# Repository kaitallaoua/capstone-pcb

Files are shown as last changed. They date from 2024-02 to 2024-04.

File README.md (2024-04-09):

# Analog Circuit Reliability for Low Earth Orbit Space Applications

In collaboration with the University of Saskatchewan, we are contributing a payload board
for the CubeSats Initiative in Canada for STEM (CUBICS). A CubeSat is a low cost, small
and approachable design for students “to engage in an end-to-end space mission
adapted to their needs and their level of comfort, expertise and readiness” (asc-csa.
gc.ca). Our payload studies the effects of space radiation on commonly used surface
mount analog Integrated Circuits (IC’s) in Low Earth Orbit (LEO). We compare different
shielding to see which provides a better effectiveness to weight ratio.

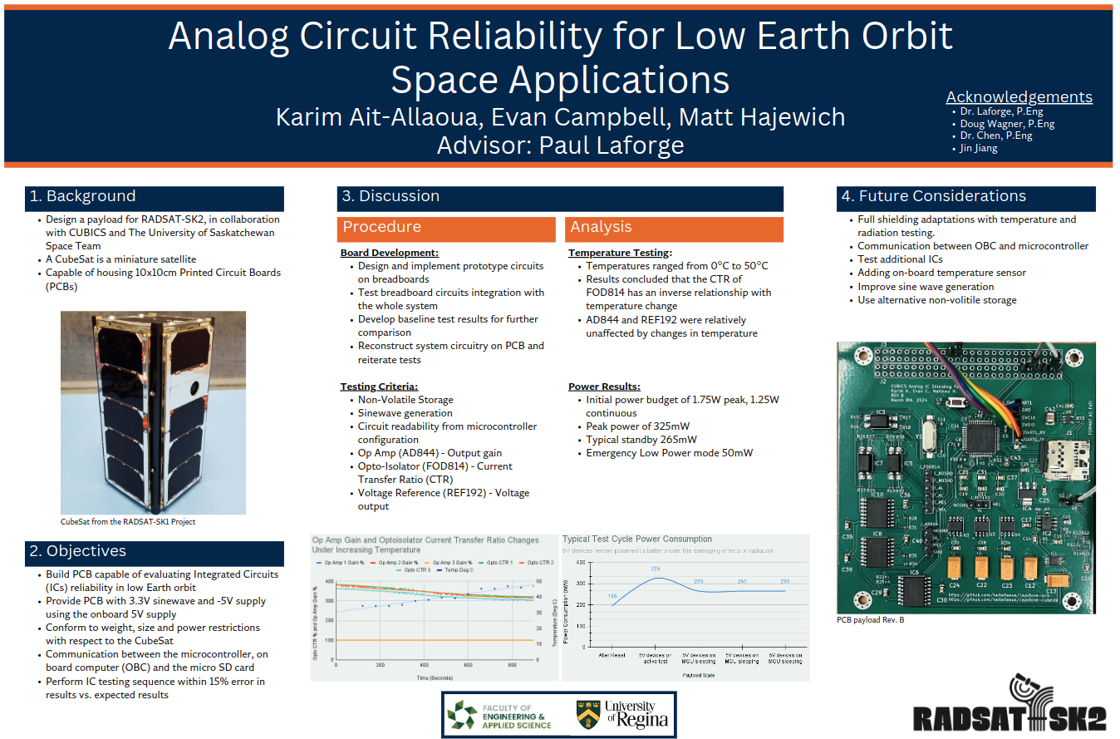
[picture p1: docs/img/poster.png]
poster


## Software

Available [here](https://github.com/kaitallaoua/capstone-cubeide)

## Setup

This project used KiCad `Version: 7.0.11-7.0.11~ubuntu22.04.1, release build` and a mix of windows builds.
Download KiCad [here](https://www.kicad.org/download/). KiCad 8 likely does work and I recommend you use it.

## Workflow

TBD (remove this once done): Someone needs to fork this repo to make further contributions to the project. Using an organization is best, I think UofS space team has one, maybe Regina team should make one? Regardless I will not be reviewing and accepting PR's to this repo.

Because using git for KiCad is like tracking binary files, I recommend to NOT rely on git handling merge conflicts. Avoid them entirely by letting only one person make changes on one branch at a time, make a PR, approve and merge and repeat and pass the baton to someone else to make changes.

## TODO

- Get I2C working (unlikely any KiCad changes)
- Get sinewave generation working 
- Add Voltage regulator
- Triple check we fit in PC104, on RADSAT-SK1 printout we dont fit in all holes, also supposed to be some notches?
- Optional: Use solder-attched external non volatile storage such as FLASH, EEPROM (or solder/glue micro sd down??)

The most substantial changes the sinwave generation. This task was assigned to Evan. Ultimately we could not get it working, thus I recommend to use a PWM wave gen from the mcu, likely add pre-amplification + current buffering, and pass it to a sharp drop off filter. The filter could be a dedicated one (probably better) or an op-amp driven one (butterworth?, wont have as good drop off without many stages).

UofRobotics is also making a PCB for their robot whose base is forked from this project, they may be a good reference for questions or idea sharing.

## Manufacturing

We used JLCPCB for `REV A` and `REV B` with great results. We also have nearly all parts ready for another revision. AT LEAST ONE MORE REVISION IS NEEDED SINCE THE FOLLOWING WERE FIXED AFTER `REV B`:

- IC1 footprint solder mask was incorrectly removed
- Micro SD card holder was facing the wrong way

Our manufacturing procedure was as follows:

Order from JLC (1 week delivery), Order from Mouser/Digikey (2-4 day delivery) -> Have all parts -> Go to ED435, use microscope, have one person assist finding parts, one pick+place, apply solder paste (min 4-5 hours)-> place in oven -> done

I recommend to use the parts list available from JLCPCB or PCBWay to assemble as much of the board for you as possible, it saves alot of time but honestly building it by hand it also not that bad. Either is fine.

## Resources

[KiCad 6 STM32 PCB Design Full Tutorial - Phil's Lab #65](https://www.youtube.com/watch?v=aVUqaB0IMh4)

[PCB Design Final Touches (Tips & Checklist) - Phil's Lab #131](https://www.youtube.com/watch?v=g4m91gv-4oQ)

## Front PCB

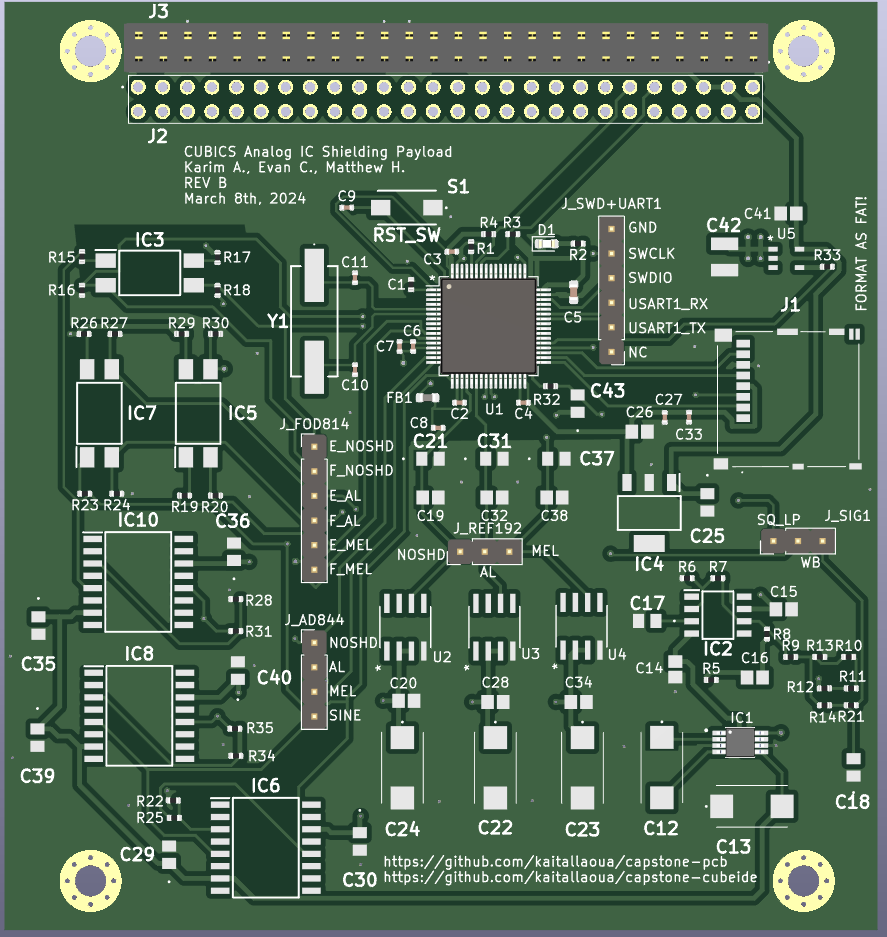
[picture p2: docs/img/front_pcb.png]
front_pcb


## Back PCB

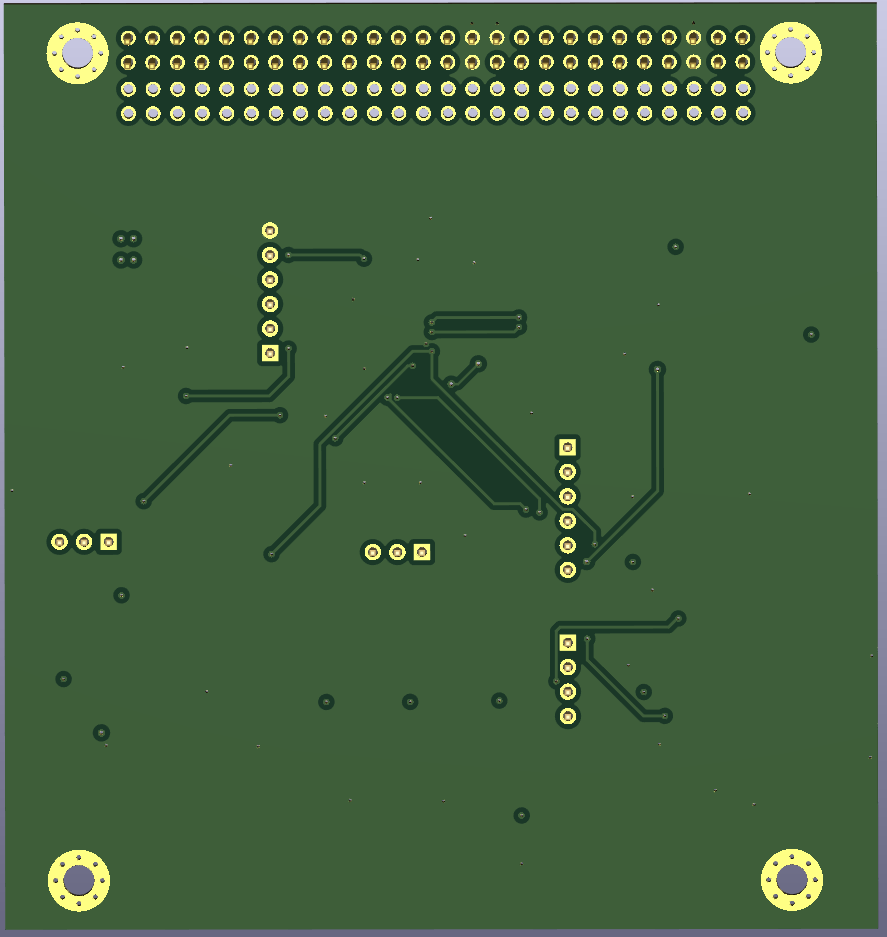
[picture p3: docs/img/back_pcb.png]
back_pcb


## Front Copper Layer

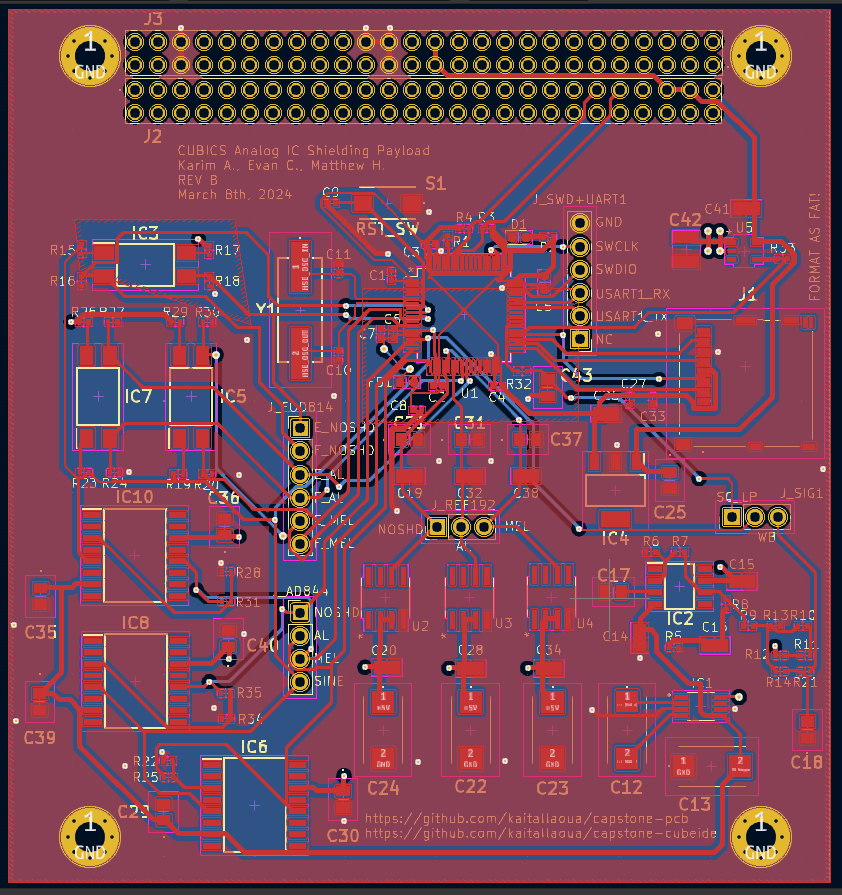
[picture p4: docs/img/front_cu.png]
front_cu


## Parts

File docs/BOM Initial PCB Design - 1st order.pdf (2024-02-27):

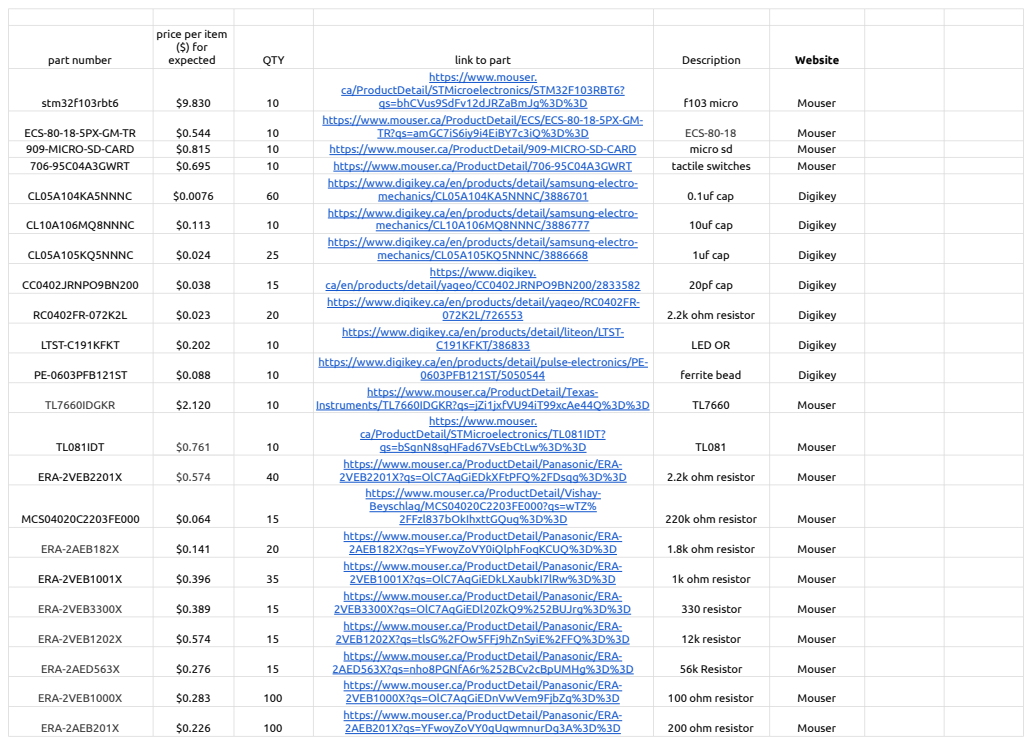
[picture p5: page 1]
part number; QTY; link to part; Description; Website; stm32f103rbt6; qs=bhCVus9SdFv12dJRZaBmJg%3D%3D; f103 micro; Mouser; ECS-80-18-5PX-GM-TR; TR?qs=amGC7iS6iy9i4EiBY7c3iQ%3D%3D; ECS-80-18; 909-MICRO-SD-CARD; https://www.mouser.ca/ProductDetail/909-MICRO-SD-CARD; micro sd; 706-95C04A3GWRT; https://www.mouser.ca/ProductDetail/706-95C04A3GWRT; tactile switches; CL05A104KA5NNNC; mechanics/CL05A104KA5NNNC/3886701; 0.1uf cap; Digikey; CL10A106MQ8NNNC; mechanics/CL10A106MQ8NNNC/3886777; 10uf cap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

price per item
($) for
expected

https://www.mouser.

ca/ProductDetail/STMicroelectronics/STM32F103RBT6?

https://www.mouser.ca/ProductDetail/ECS/ECS-80-18-5PX-GM-

https://www.digikey.ca/en/products/detail/samsung-electro-

https://www.digikey.

https://www.digikey.ca/en/products/detail/yageo/RC0402FR-

https://www.digikey.ca/en/products/detail/liteon/LTST-

https://www.digikey.ca/en/products/detail/pulse-electronics/PE-

https://www.mouser.ca/ProductDetail/Texas-

ca/ProductDetail/STMicroelectronics/TL081IDT?

https://www.mouser.ca/ProductDetail/Panasonic/ERA-
https://www.mouser.ca/ProductDetail/Vishay-
Beyschlag/MCS04020C2203FE000?qs=wTZ%

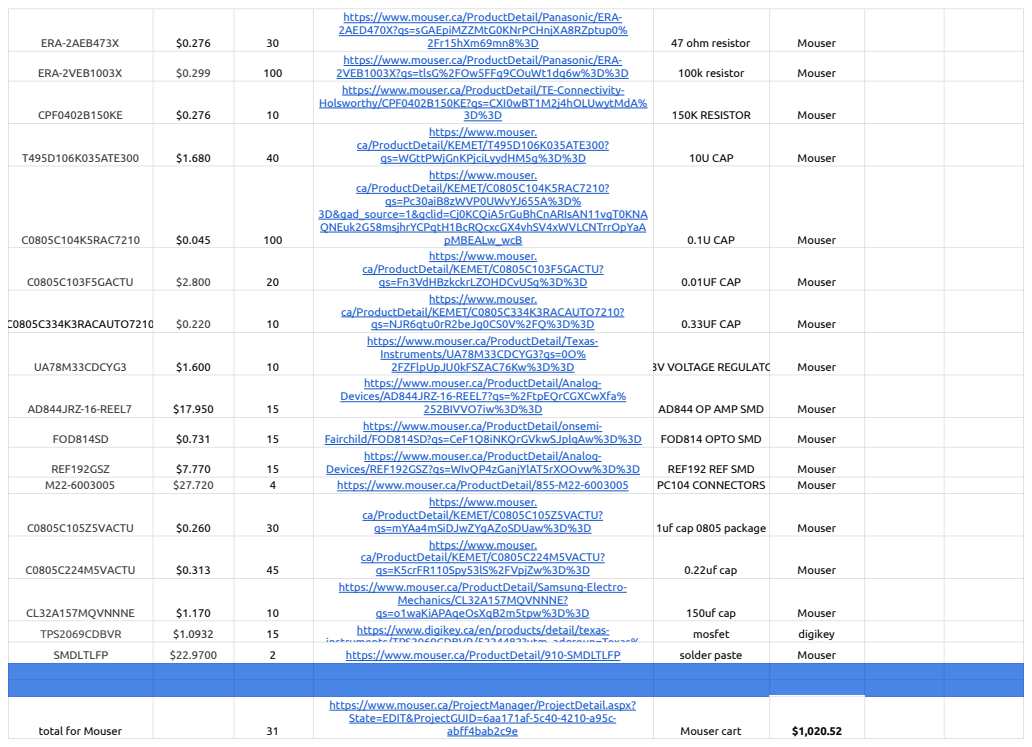
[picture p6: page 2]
ERA-2AEB473X; 2Fr15hXm69mn8%3D; 47 ohm resistor; Mouser; ERA-2VEB1003X; 2VEB1003X?qs=tlsG%2FOw5FFg9COuWt1dq6w%3D%3D; 100k resistor; CPF0402B150KE; 150K RESISTOR; T495D106K035ATE300; qs=WGttPWjGnKPjciLyydHM5g%3D%3D; 10U CAP; C0805C104K5RAC7210; 3D&gad_source=1&gclid=Cj0KCQiA5rGuBhCnARIsAN11vgT0KNA QNEuk2G58msjhrYCPqtH1BcRQcxcGX4vhSV4xWVLCNTrrOpYaA; pMBEALw_wcB; 0.1U CAP; C0805C103F5GACTU; qs=Fn3VdHBzkckrLZOHDCvUSg%3D%3D; 0.01UF CAP; C0805C334K3RACAUTO7210; qs=NJR6qtu0rR2beJg0CS0V%2FQ%3D%3D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

https://www.mouser.ca/ProductDetail/Panasonic/ERA-
2AED470X?qs=sGAEpiMZZMtG0KNrPCHnjXA8RZptup0%

https://www.mouser.ca/ProductDetail/TE-Connectivity-
Holsworthy/CPF0402B150KE?qs=CXI0wBT1M2j4hOLUwytMdA%

https://www.mouser.

ca/ProductDetail/KEMET/T495D106K035ATE300?

ca/ProductDetail/KEMET/C0805C104K5RAC7210?
qs=Pc30aiB8zWVP0UWvYJ655A%3D%

ca/ProductDetail/KEMET/C0805C103F5GACTU?

ca/ProductDetail/KEMET/C0805C334K3RACAUTO7210?
https://www.mouser.ca/ProductDetail/Texas-
Instruments/UA78M33CDCYG3?qs=0O%
https://www.mouser.ca/ProductDetail/Analog-
Devices/AD844JRZ-16-REEL7?qs=%2FtpEQrCGXCwXfa%

https://www.mouser.ca/ProductDetail/onsemi-

ca/ProductDetail/KEMET/C0805C105Z5VACTU?

ca/ProductDetail/KEMET/C0805C224M5VACTU?

https://www.mouser.ca/ProductDetail/Samsung-Electro-

https://www.mouser.ca/ProjectManager/ProjectDetail.aspx?
State=EDIT&ProjectGUID=6aa171af-5c40-4210-a95c-

total for Digikey | 8 | https://www.digikey.ca/short/bmjnbp47 | Digikey cart | 33.18
total cart | 39 | TOTAL | $1,053.70 | Tax might not | be included

https://www.mouser.
ca/ProductDetail/KEMET/C0805C334K3RACAUTO?
qs=sSYV1F9c5cFAGgBePUAC4A%3D%3D (https://www.mouser.ca/ProductDetail/KEMET/C0805C334K3RACAUTO?qs=sSYV1F9c5cFAGgBePUAC4A%3D%3D) | .33uf new

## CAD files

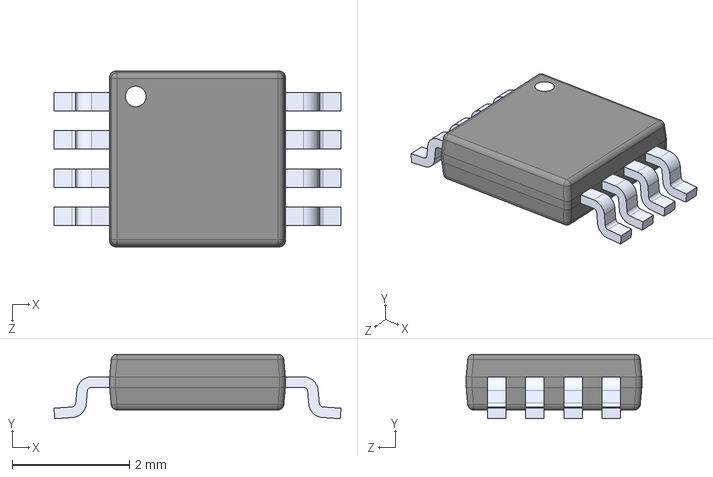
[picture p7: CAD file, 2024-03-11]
footprint_3d/TL7660IDGKR.step
4.90 x 1.10 x 3.00 mm

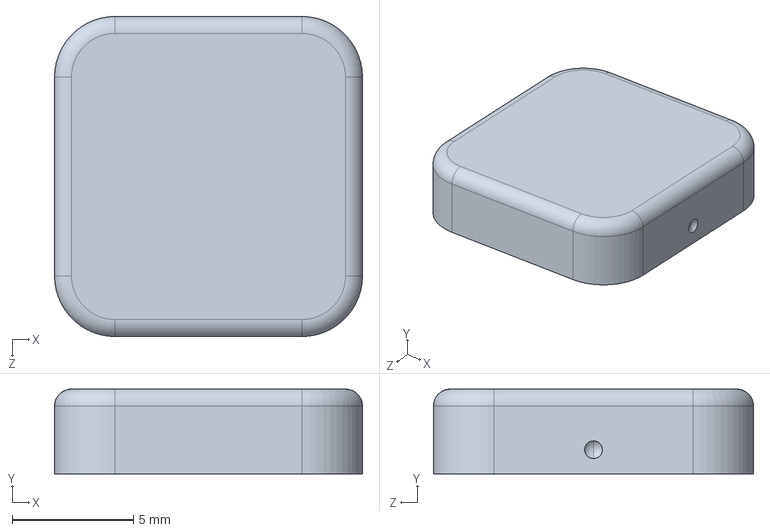
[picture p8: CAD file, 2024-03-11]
footprint_3d/MS128-10C.step
12.7 x 3.50 x 13.2 mm

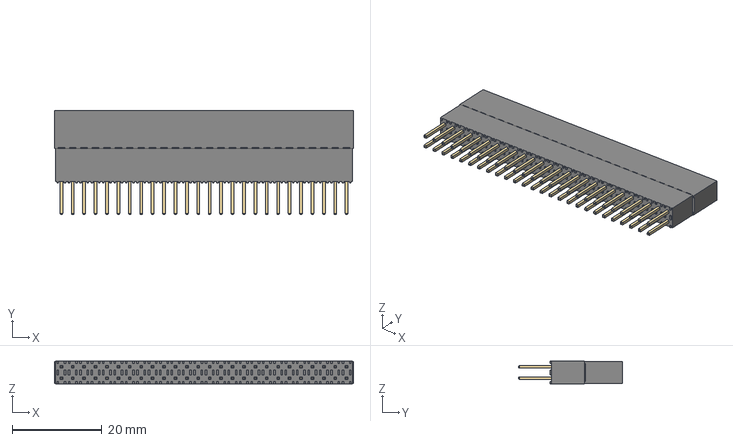
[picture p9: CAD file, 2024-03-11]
footprint_3d/ESQ-126-39-L-D.stp
66.5 x 23.2 x 5.08 mm

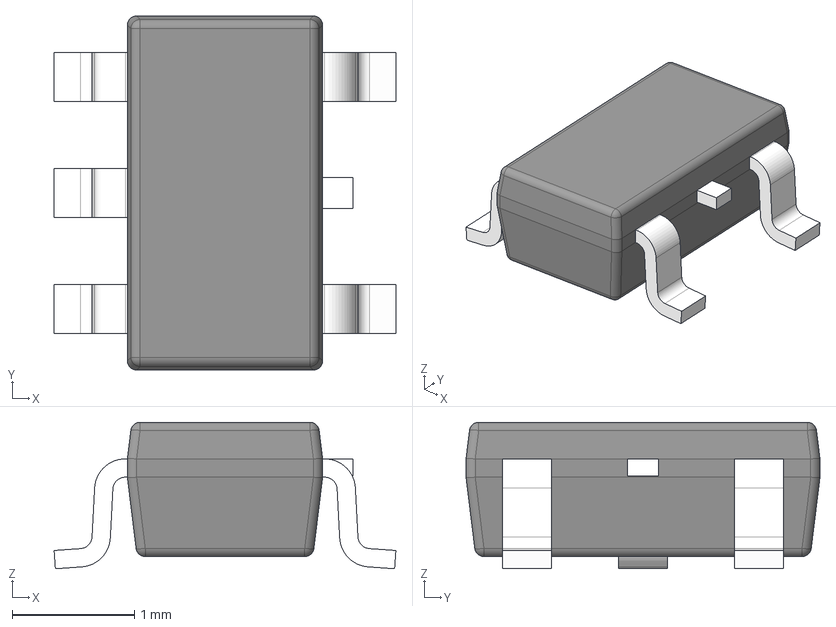
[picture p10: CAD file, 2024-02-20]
footprint_3d/DBV0005A-MF.stp
2.80 x 2.90 x 1.20 mm
BODY-SOT
LEAD-SOT x 5
LEAD-DUMMY

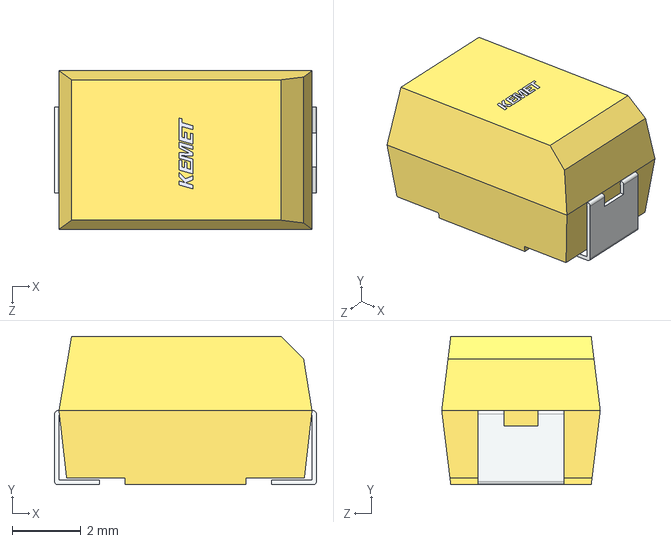
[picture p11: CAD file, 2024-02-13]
footprint_3d/T495X106K050ATE250-10u.stp
7.60 x 4.31 x 4.60 mm

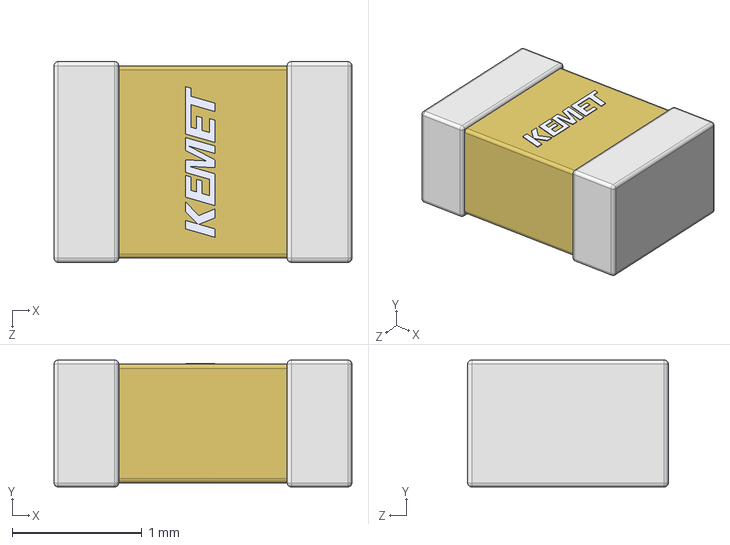
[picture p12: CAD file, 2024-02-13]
footprint_3d/C0805C224M5VACTU-0.22u.stp
2.30 x 0.98 x 1.55 mm

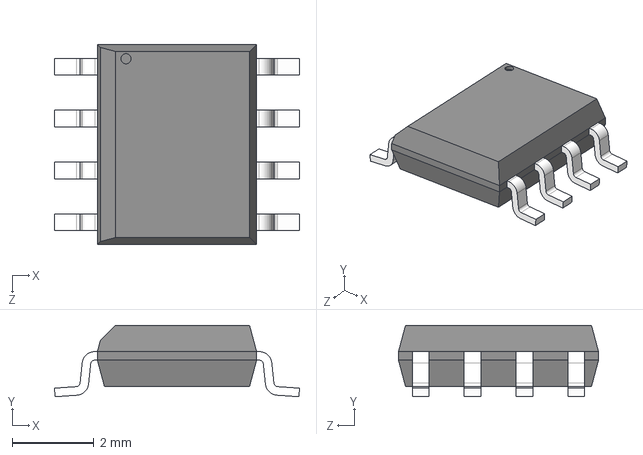
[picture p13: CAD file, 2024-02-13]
footprint_3d/REF192GSZ.step
6.00 x 1.75 x 4.90 mm

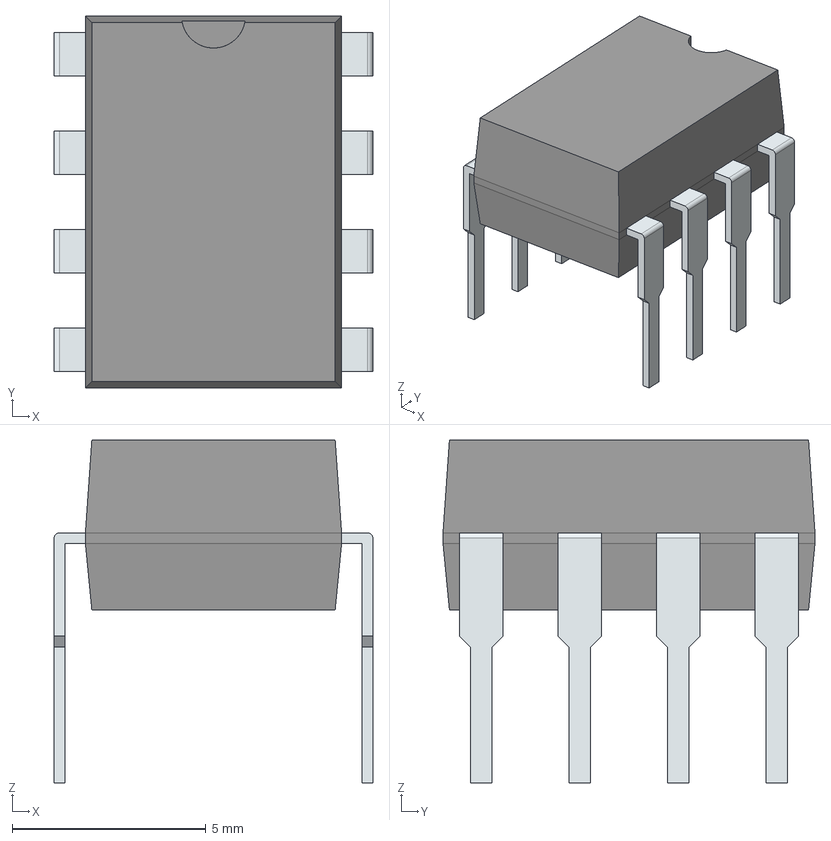
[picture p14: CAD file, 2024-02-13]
footprint_3d/AD844ANZ.stp
8.22 x 9.59 x 8.83 mm
PinsArrayLR

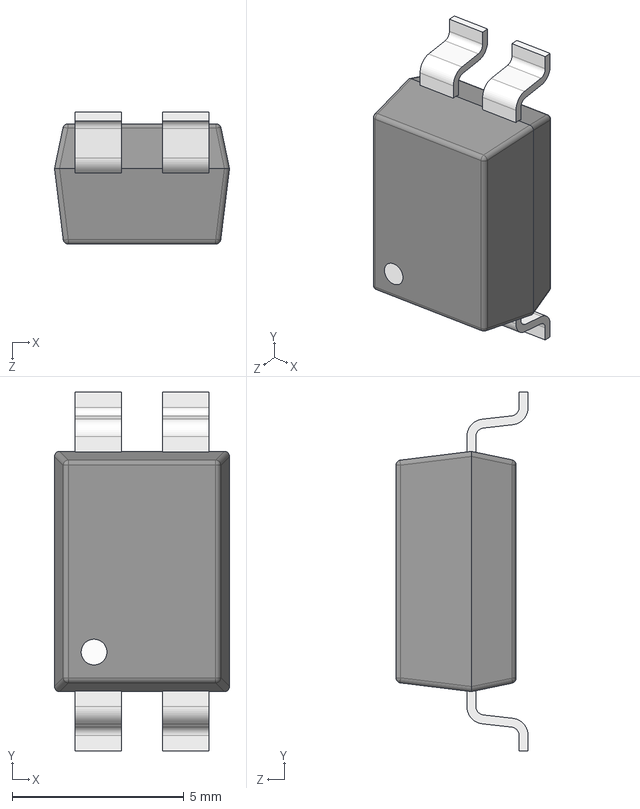
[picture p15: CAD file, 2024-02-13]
footprint_3d/FOD814SD.stp
5.10 x 10.5 x 3.85 mm

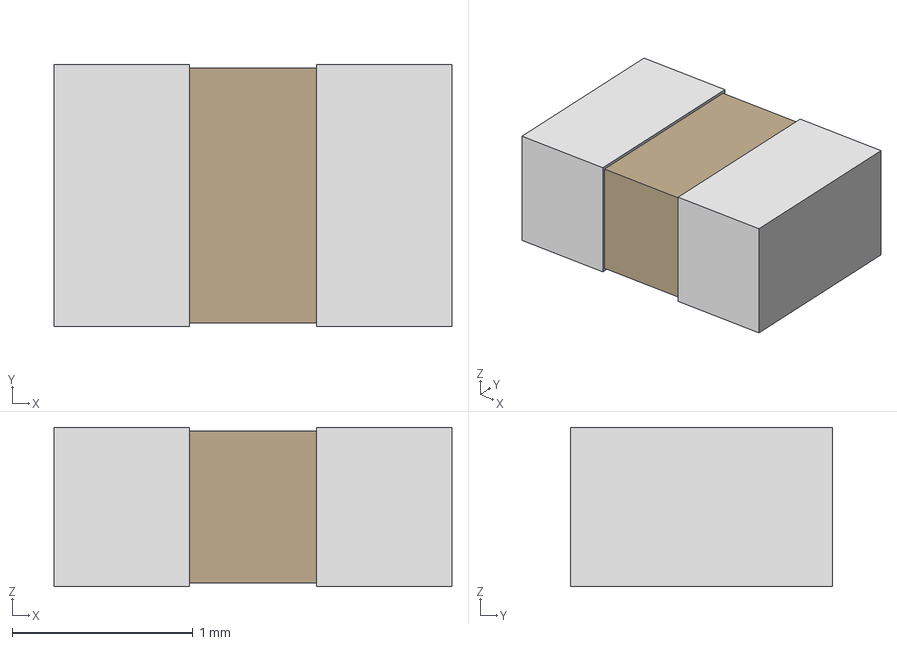
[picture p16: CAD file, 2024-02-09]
footprint_3d/CAPC220145_88N_KEM.step
2.20 x 1.45 x 0.88 mm

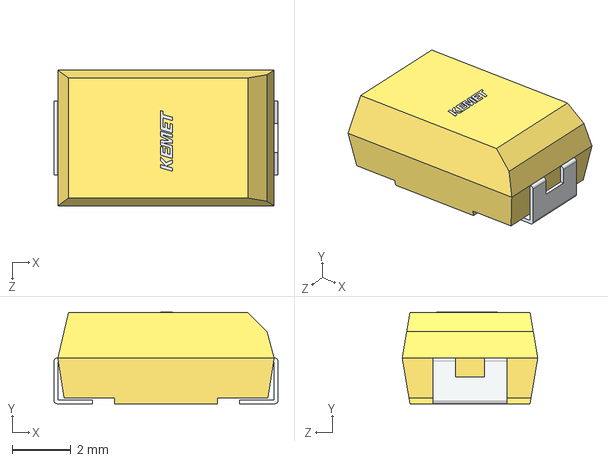
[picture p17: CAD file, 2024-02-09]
footprint_3d/T495D106K035ATE300.stp
7.60 x 3.11 x 4.60 mm

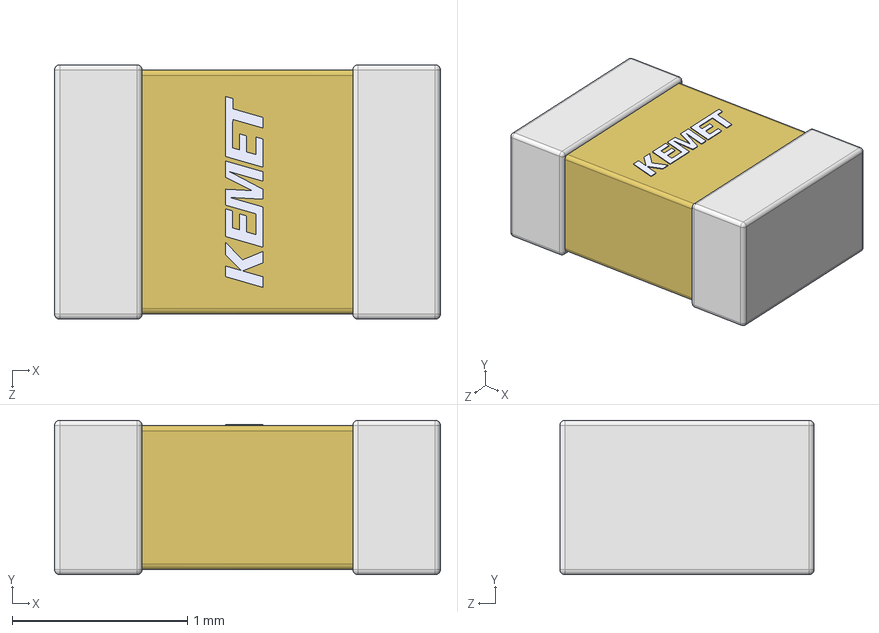
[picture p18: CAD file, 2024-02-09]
footprint_3d/C0805C103F5GACTU.stp
2.20 x 0.88 x 1.45 mm

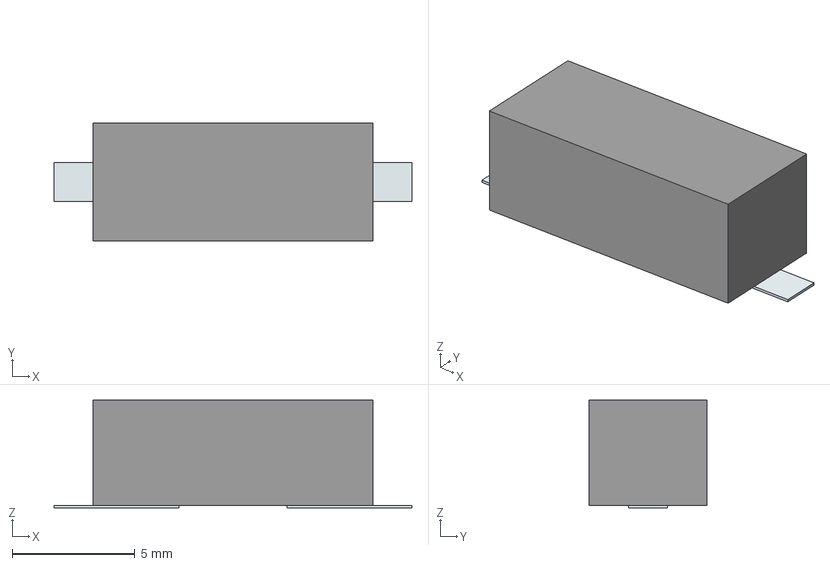
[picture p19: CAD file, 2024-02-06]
footprint_3d/ECS-80-18-5PX-GM-TR.stp
14.6 x 4.80 x 4.40 mm
Pins

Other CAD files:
footprint_3d/TL081IDT.stp

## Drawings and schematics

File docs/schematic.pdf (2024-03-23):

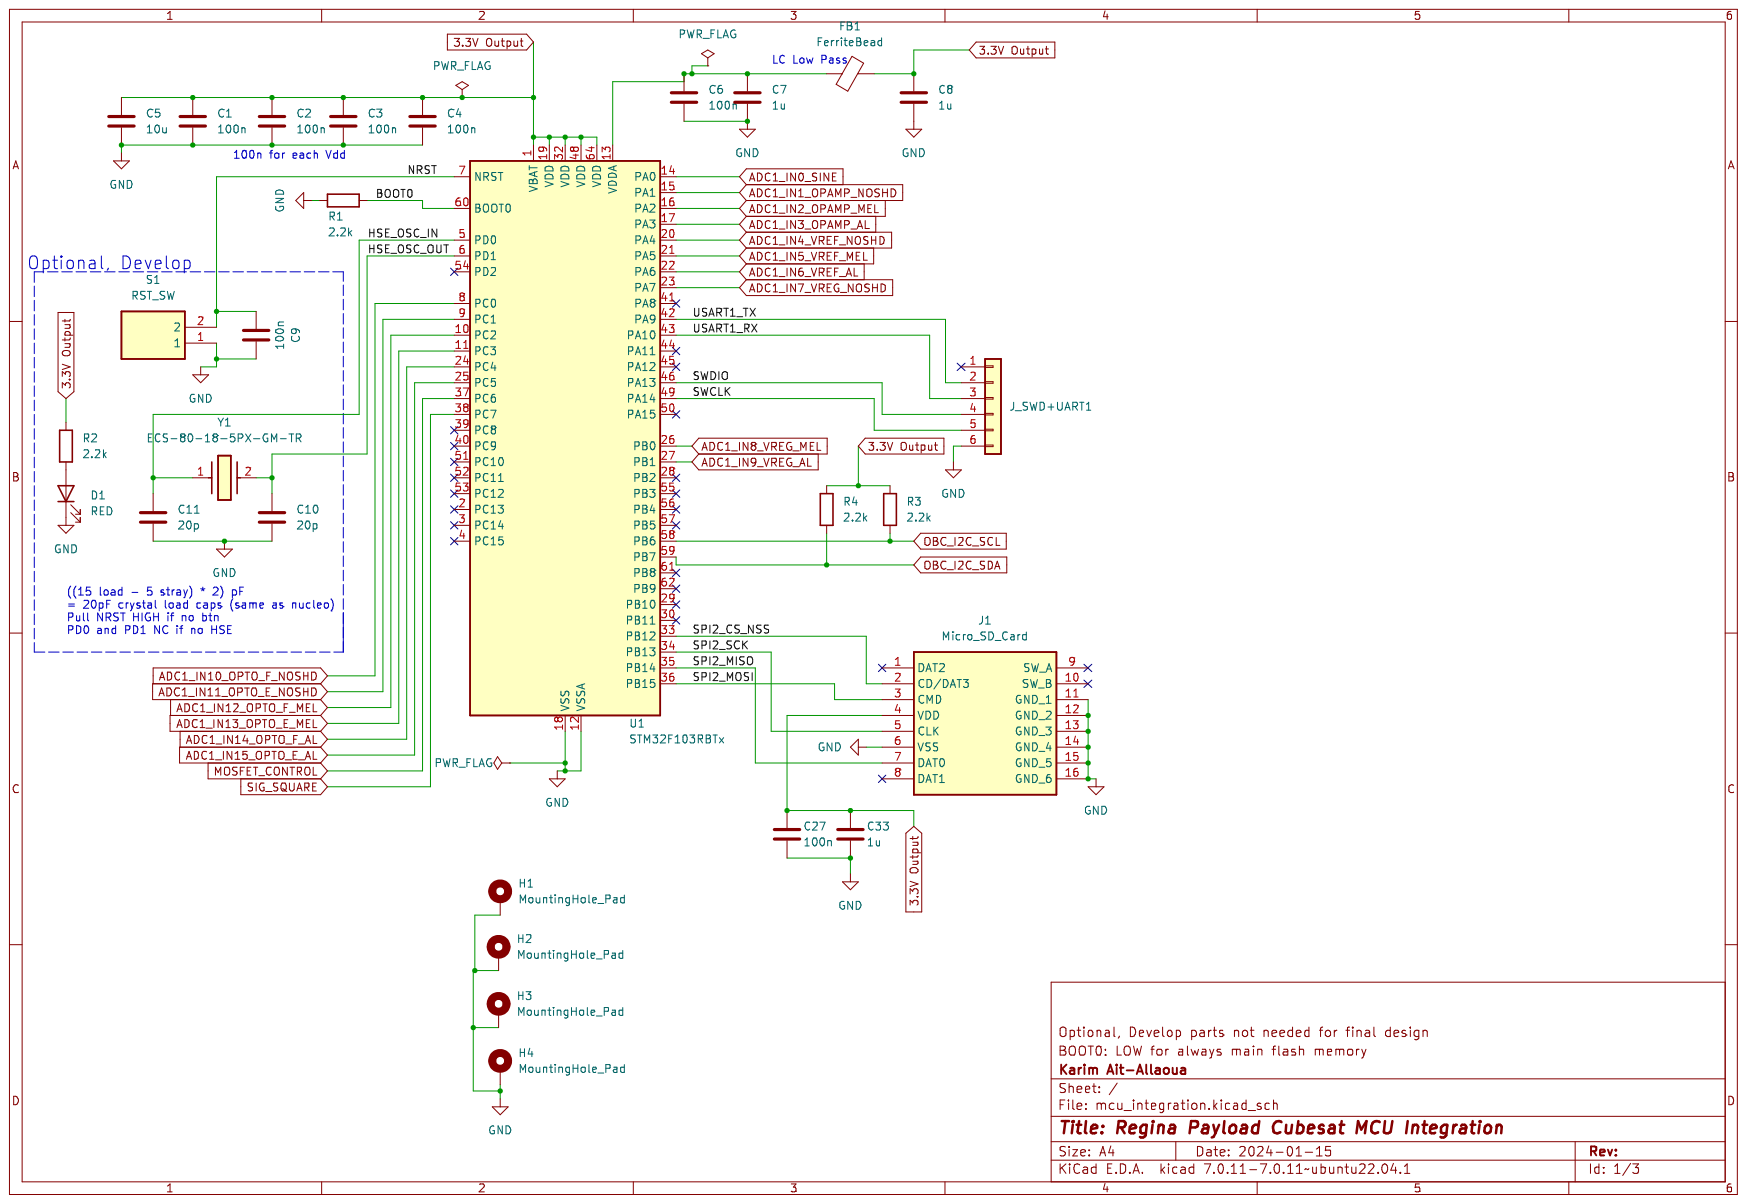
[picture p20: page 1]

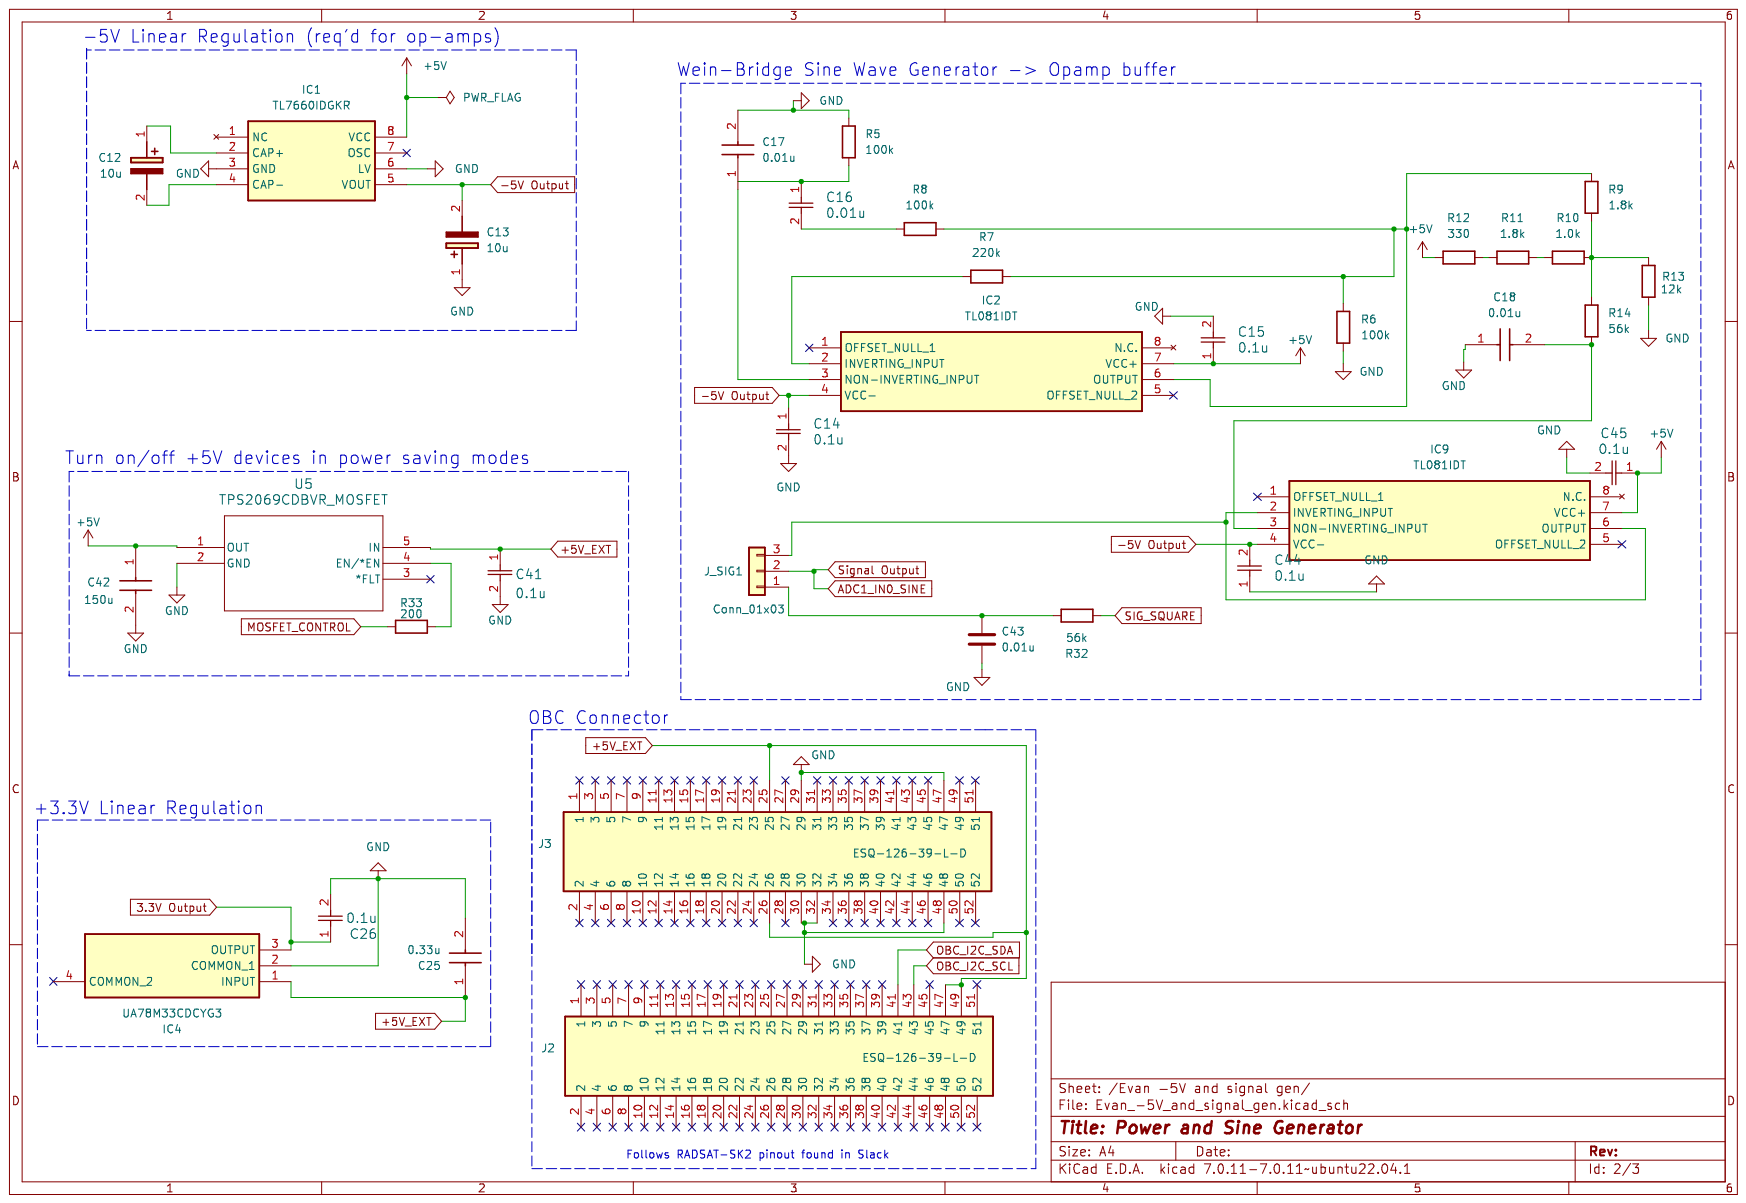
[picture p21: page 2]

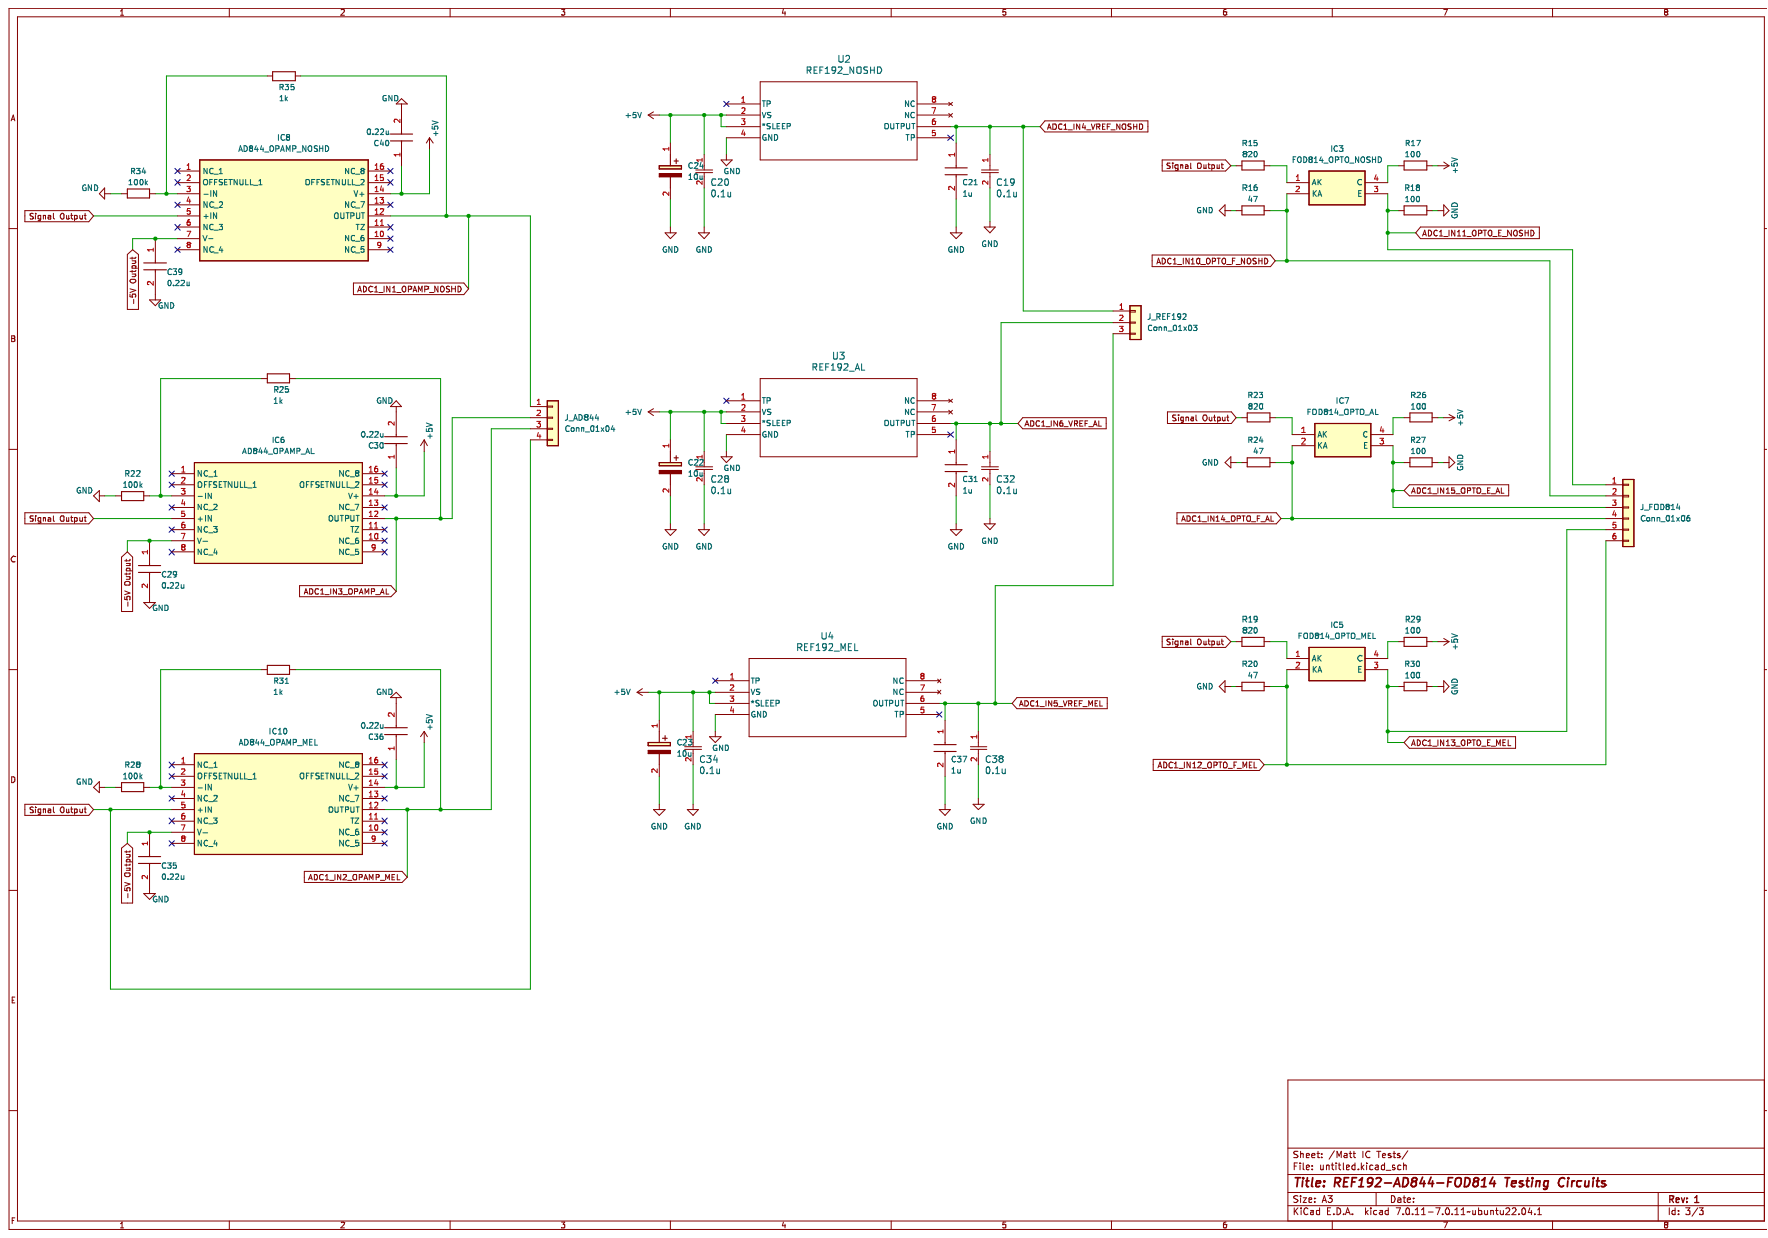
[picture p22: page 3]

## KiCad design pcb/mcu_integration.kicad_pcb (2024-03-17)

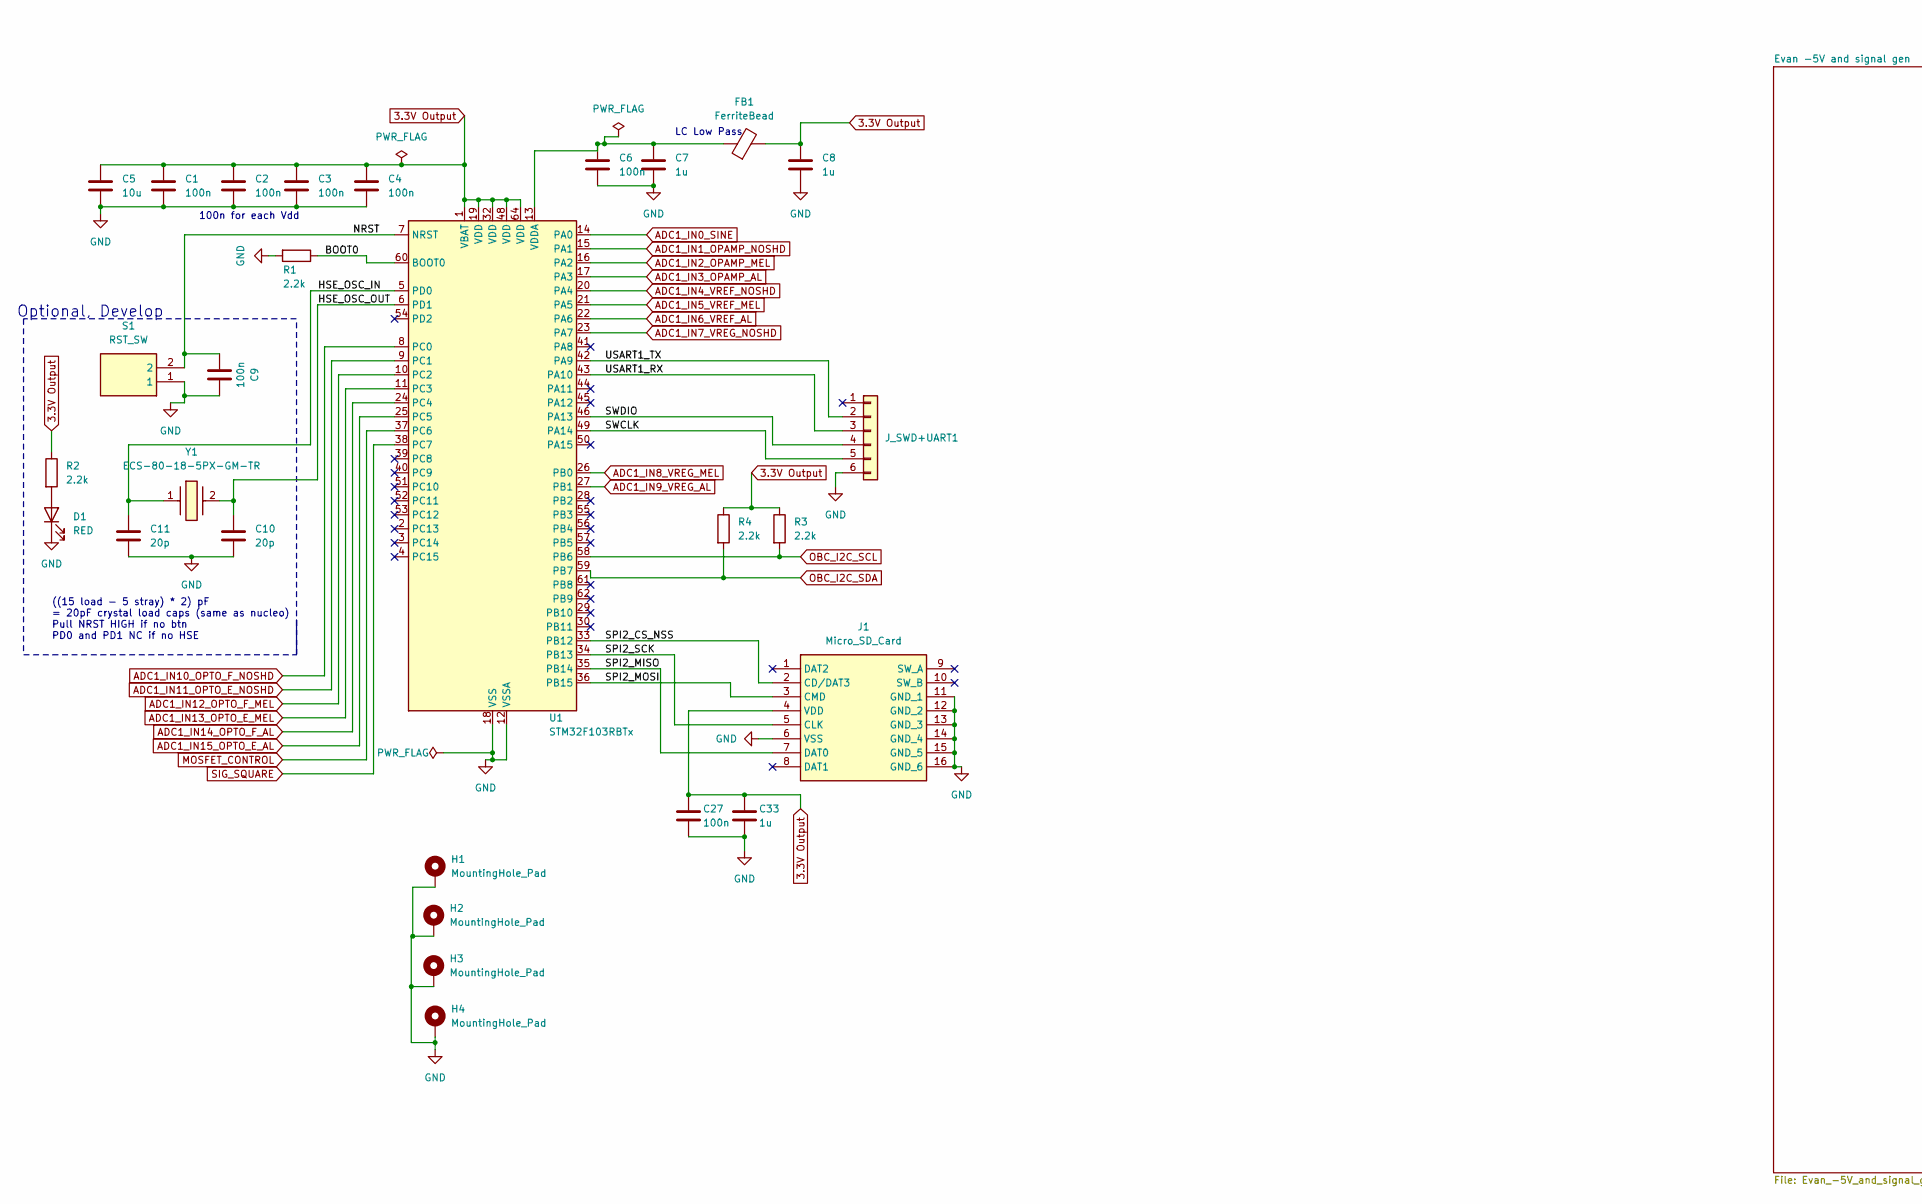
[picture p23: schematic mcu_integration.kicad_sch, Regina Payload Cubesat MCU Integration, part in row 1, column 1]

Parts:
C1: 100n; R_0402_1005Metric
C2, C3, C4, C6, C9, C27: 100n; C_0402_1005Metric
C5: 10u; C_0603_1608Metric
C7, C8, C33: 1u; C_0402_1005Metric
C10, C11: 20p; C_0402_1005Metric
D1: RED; LED_0603_1608Metric
FB1: FerriteBead; L_0603_1608Metric
H1, H2, H3, H4: MountingHole_Pad; MountingHole_3.2mm_M3_Pad_Via
J1: Micro_SD_Card; 22017781; Mouser Part Number 571-2201778-1
J_SWD+UART1: Conn_01x06; PinHeader_1x06_P2.54mm_Vertical
R1, R2, R3, R4: 2.2k; R_0402_1005Metric
S1: RST_SW; 95C04A3GWRT; Mouser Part Number 706-95C04A3GWRT
U1: STM32F103RBTx; LQFP-64_10x10mm_P0.5mm
Y1: ECS-80-18-5PX-GM-TR; ECS80185PXGMTR; Mouser Part Number 520-80-18-5PX-GM-TR

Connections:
3.3V Output: C1.1, C2.1, C3.1, C4.1, C5.1, C8.1, C27.1, C33.1, FB1.2, J1.4 (VDD), R2.1, R3.1, R4.1, U1.1 (VBAT), U1.19 (VDD), U1.32 (VDD), U1.48 (VDD), U1.64 (VDD); also elsewhere on the board
/BOOT0: R1.1, U1.60 (BOOT0)
/HSE_OSC_IN: C11.1, U1.5 (PD0), Y1.1
/HSE_OSC_OUT: C10.1, U1.6 (PD1), Y1.2
/NRST: C9.2, S1.2, U1.7 (NRST)
/SPI2_CS_NSS: J1.2 (CD/DAT3), U1.33 (PB12)
/SPI2_MISO: J1.7 (DAT0), U1.35 (PB14)
/SPI2_MOSI: J1.3 (CMD), U1.36 (PB15)
/SPI2_SCK: J1.5 (CLK), U1.34 (PB13)
/SWCLK: J_SWD+UART1.5, U1.49 (PA14)
/SWDIO: J_SWD+UART1.4, U1.46 (PA13)
/USART1_RX: J_SWD+UART1.3, U1.43 (PA10)
/USART1_TX: J_SWD+UART1.2, U1.42 (PA9)
ADC1_IN0_SINE: U1.14 (PA0); also elsewhere on the board
ADC1_IN1_OPAMP_NOSHD: U1.15 (PA1); also elsewhere on the board
ADC1_IN2_OPAMP_MEL: U1.16 (PA2); also elsewhere on the board
ADC1_IN3_OPAMP_AL: U1.17 (PA3); also elsewhere on the board
ADC1_IN4_VREF_NOSHD: U1.20 (PA4); also elsewhere on the board
ADC1_IN5_VREF_MEL: U1.21 (PA5); also elsewhere on the board
ADC1_IN6_VREF_AL: U1.22 (PA6); also elsewhere on the board
ADC1_IN7_VREG_NOSHD: U1.23 (PA7)
ADC1_IN8_VREG_MEL: U1.26 (PB0)
ADC1_IN9_VREG_AL: U1.27 (PB1)
ADC1_IN10_OPTO_F_NOSHD: U1.8 (PC0); also elsewhere on the board
ADC1_IN11_OPTO_E_NOSHD: U1.9 (PC1); also elsewhere on the board
ADC1_IN12_OPTO_F_MEL: U1.10 (PC2); also elsewhere on the board
ADC1_IN13_OPTO_E_MEL: U1.11 (PC3); also elsewhere on the board
ADC1_IN14_OPTO_F_AL: U1.24 (PC4); also elsewhere on the board
ADC1_IN15_OPTO_E_AL: U1.25 (PC5); also elsewhere on the board
GND: C1.2, C2.2, C3.2, C4.2, C5.2, C6.2, C7.2, C8.2, C9.1, C10.2, C11.2, C27.2, C33.2, D1.1 (K), H1.1, H2.1, H3.1, H4.1, J1.6 (VSS), J1.11 (GND_1), J1.12 (GND_2), J1.13 (GND_3), J1.14 (GND_4), J1.15 (GND_5), J1.16 (GND_6), J_SWD+UART1.6, R1.2, S1.1, U1.12 (VSSA), U1.18 (VSS), U1.31 (VSS), U1.47 (VSS), U1.63 (VSS); also elsewhere on the board
MOSFET_CONTROL: U1.37 (PC6); also elsewhere on the board
unnamed: D1.2 (A), R2.2
unnamed: C6.1, C7.1, FB1.1, U1.13 (VDDA)
OBC_I2C_SCL: R3.2, U1.58 (PB6); also elsewhere on the board
OBC_I2C_SDA: R4.2, U1.59 (PB7); also elsewhere on the board
SIG_SQUARE: U1.38 (PC7); also elsewhere on the board

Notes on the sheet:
((15 load - 5 stray) * 2) pF = 20pF crystal load caps (same as nucleo) Pull NRST HIGH if no btn PD0 and PD1 NC if no HSE
Optional, Develop
100n for each Vdd
LC Low Pass

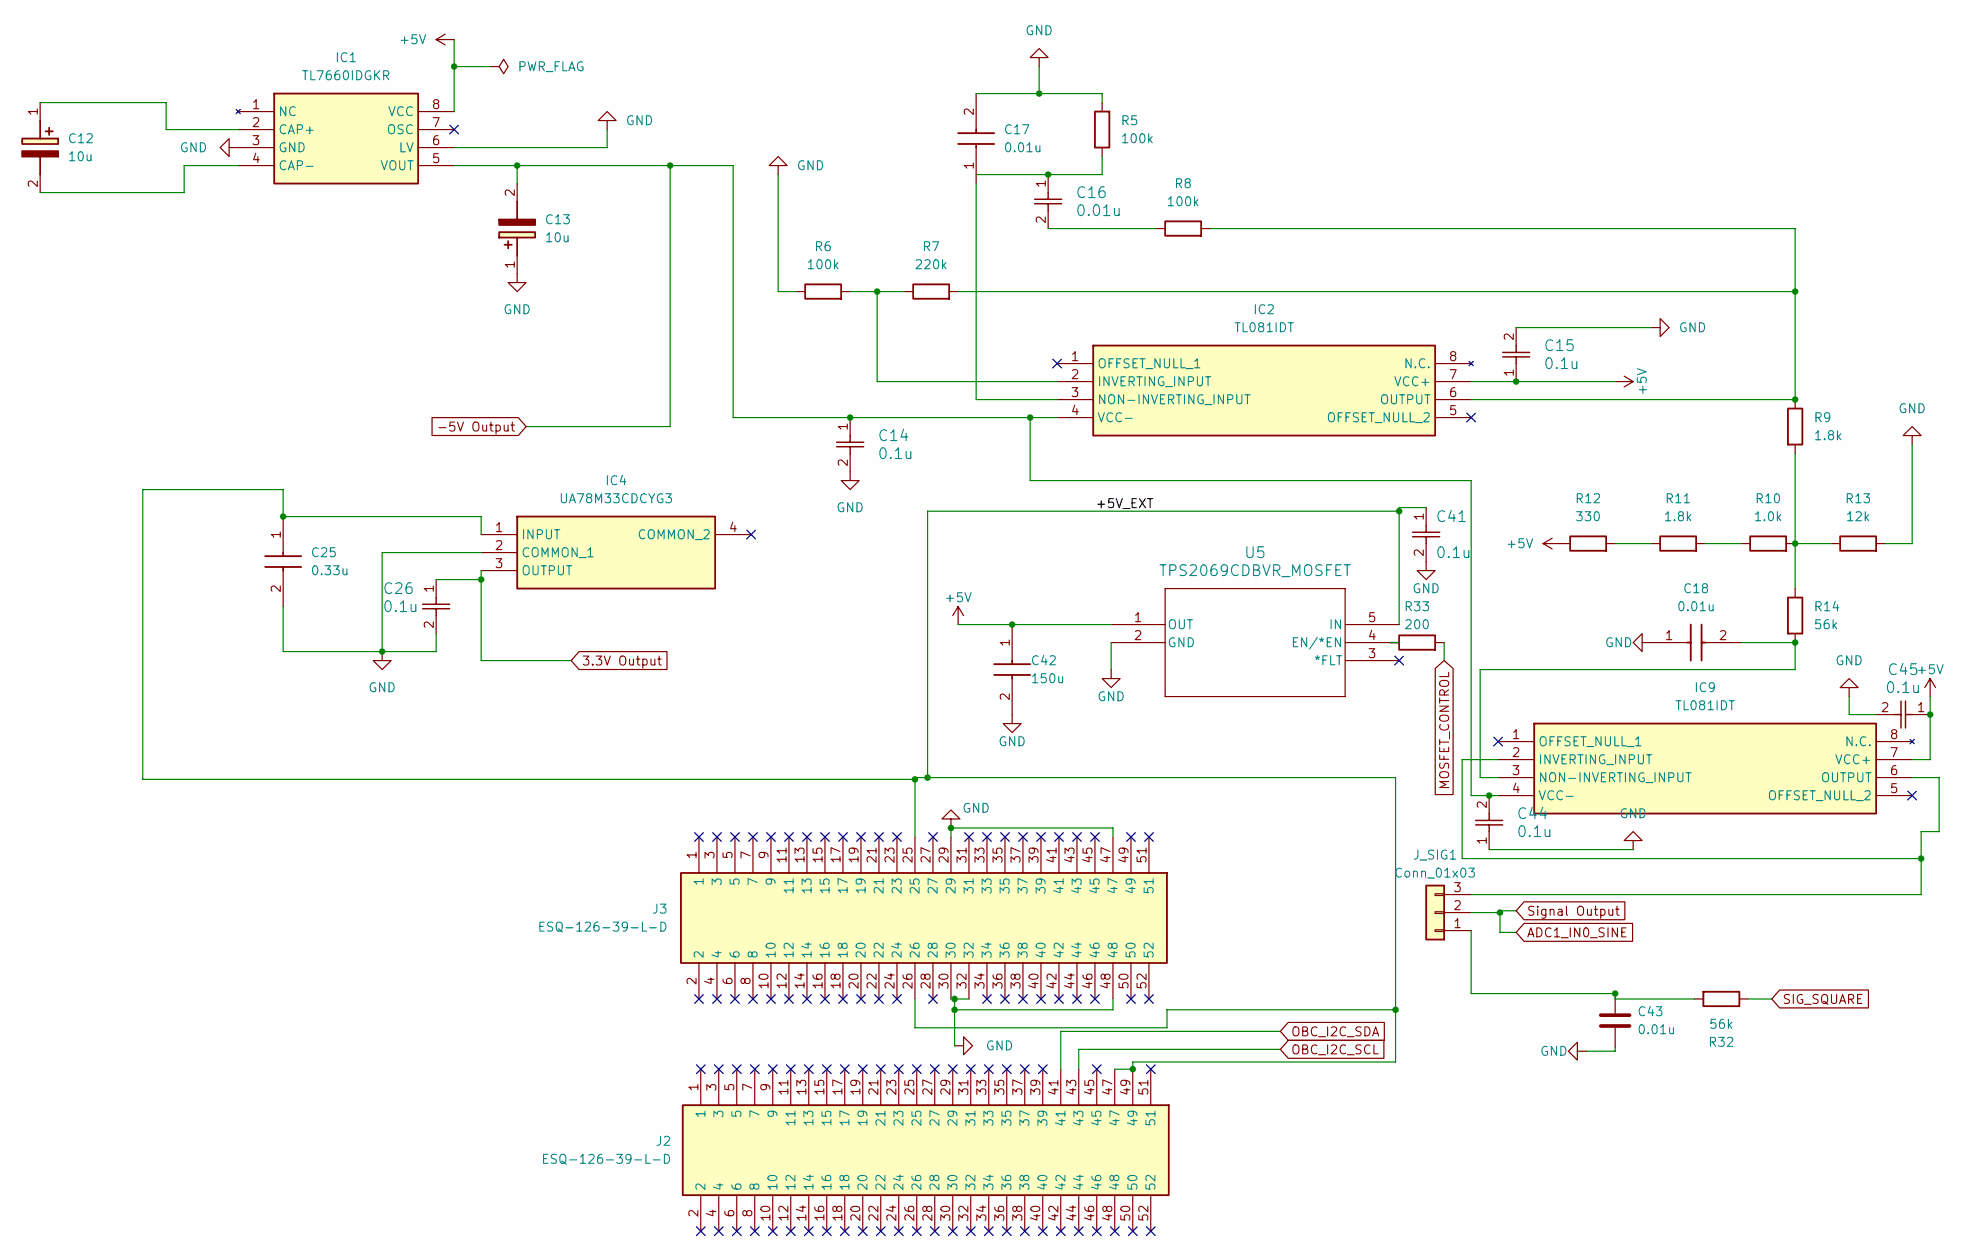
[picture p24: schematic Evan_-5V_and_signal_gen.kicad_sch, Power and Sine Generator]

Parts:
C12, C13: 10u; T495D; Mouser Part Number 80-T495D106K035
C14, C15, C26, C41, C44, C45: 0.1u; CAPC220145_88N_KEM-0.1u
C16: 0.01u; CAPC220145_88N_KEM-0.1u
C17, C18: 0.01u; C0805; Mouser Part Number 80-C0805C103F5G
C25: 0.33u; C0805; Mouser Part Number 80-C0805C334K3RAULR
C42: 150u; CAPC3225X280N_150U; Mouser Part Number 187-CL32A157MQVNNNE
C43: 0.01u; C0805
IC1: TL7660IDGKR; SOP65P490X110-8N-actual; Mouser Part Number 595-TL7660IDGKR
IC2, IC9: TL081IDT; SOIC127P600X175-8N; Mouser Part Number 511-TL081IDT
IC4: UA78M33CDCYG3; SOT230P700X180-4N; Mouser Part Number 595-UA78M33CDCYG3
J2, J3: ESQ-126-39-L-D; ESQ-126-Y-X-D; Mouser Part Number 200-ESQ12639LD
J_SIG1: Conn_01x03; PinHeader_1x03_P2.54mm_Vertical
R5, R6, R8: 100k; R_0402_1005Metric
R7: 220k; R_0402_1005Metric
R9, R11: 1.8k; R_0402_1005Metric
R10: 1.0k; R_0402_1005Metric
R12: 330; R_0402_1005Metric
R13: 12k; R_0402_1005Metric
R14, R32: 56k; R_0402_1005Metric
R33: 200; R_0402_1005Metric
U5: TPS2069CDBVR_MOSFET; DBV5_TEX_MF

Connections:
3.3V Output: C26.1, IC4.3 (OUTPUT); also elsewhere on the board
+5V: C15.1, C42.1, C45.1, IC1.8 (VCC), IC2.7 (VCC+), IC9.7 (VCC+), R12.1, U5.1 (OUT); also elsewhere on the board
-5V Output: C13.2 (-), C14.1, C44.2, IC1.5 (VOUT), IC2.4 (VCC-), IC9.4 (VCC-); also elsewhere on the board
/Evan -5V and signal gen/+5V_EXT: C25.1, C41.1, IC4.1 (INPUT), J2.47, J2.49, J3.25, J3.26, U5.5 (IN)
ADC1_IN0_SINE: J_SIG1.2; also elsewhere on the board
GND: C13.1 (+), C14.2, C15.2, C17.2, C18.1, C25.2, C26.2, C41.2, C42.2, C43.1, C44.1, C45.2, IC1.3 (GND), IC1.6 (LV), IC4.2 (COMMON_1), J3.29, J3.30, J3.32, J3.47, J3.48, R5.2, R6.1, R13.2, U5.2 (GND); also elsewhere on the board
MOSFET_CONTROL: R33.2; also elsewhere on the board
unnamed: C12.1 (+), IC1.2 (CAP+)
unnamed: C12.2 (-), IC1.4 (CAP-)
unnamed: C16.1, R5.1
unnamed: C16.2, R8.1
unnamed: IC2.2 (INVERTING_INPUT), R6.2, R7.1
unnamed: C17.1, IC2.3 (NON-INVERTING_INPUT)
unnamed: IC2.6 (OUTPUT), R7.2, R8.2, R9.1
unnamed: IC9.2 (INVERTING_INPUT), IC9.6 (OUTPUT), J_SIG1.3
unnamed: C18.2, IC9.3 (NON-INVERTING_INPUT), R14.2
unnamed: C43.2, J_SIG1.1, R32.2
unnamed: R10.1, R11.2
unnamed: R9.2, R10.2, R13.1, R14.1
unnamed: R11.1, R12.2
unnamed: R33.1, U5.4 (EN/*EN)
OBC_I2C_SCL: J2.43; also elsewhere on the board
OBC_I2C_SDA: J2.41; also elsewhere on the board
SIG_SQUARE: R32.1; also elsewhere on the board

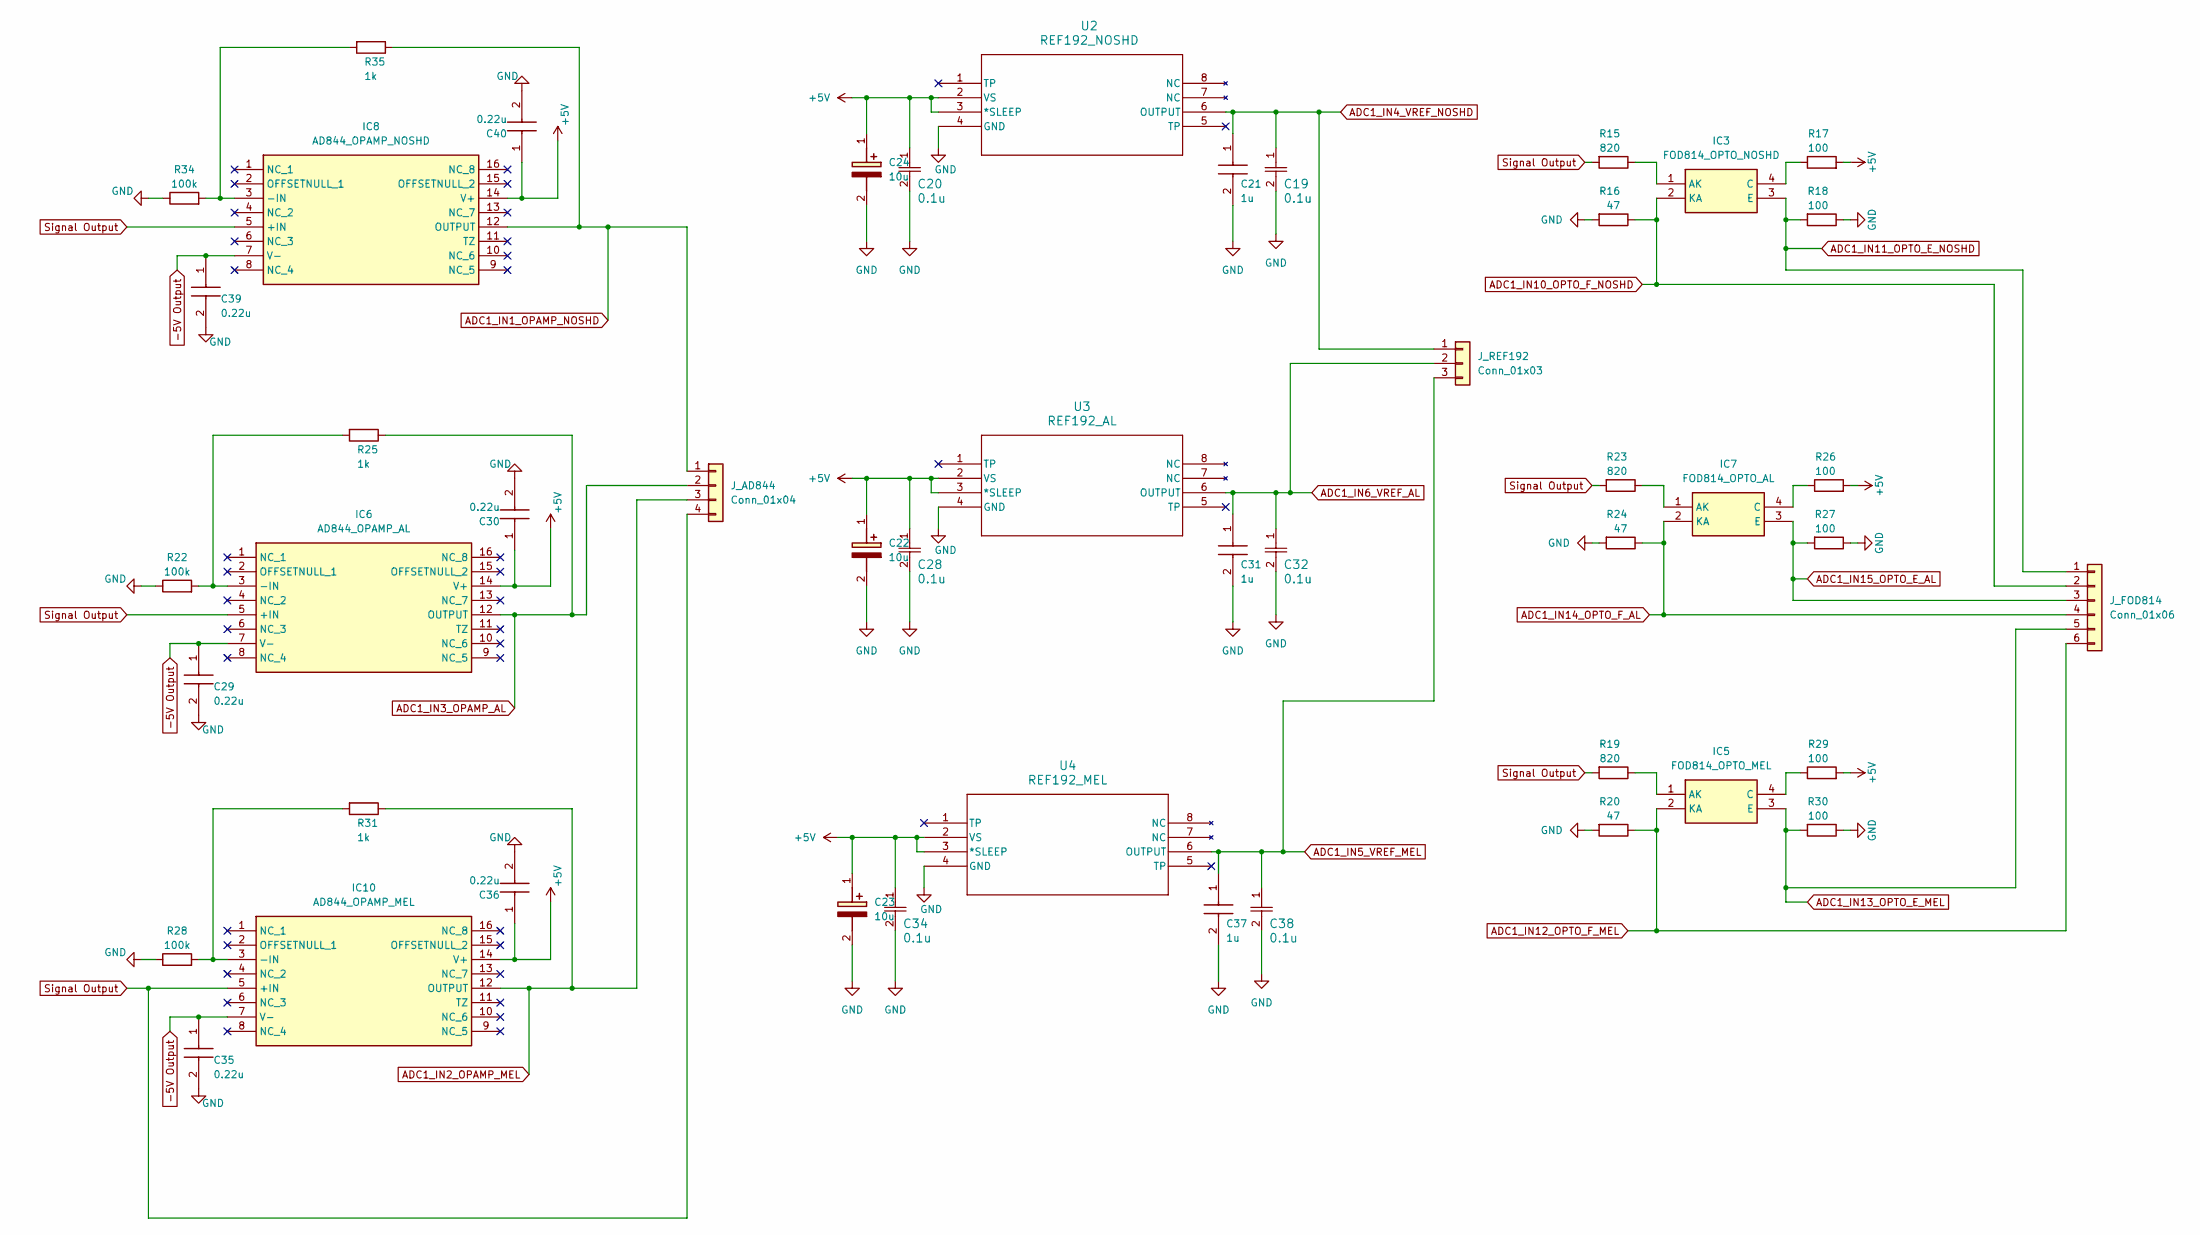
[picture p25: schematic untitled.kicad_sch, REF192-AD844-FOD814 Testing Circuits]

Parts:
C19, C20, C28, C32, C34, C38: 0.1u; CAPC220145_88N_KEM-0.1u
C21, C31, C37: 1u; C0805-1u; Mouser Part Number 80-C0805C105Z5VACTU
C22, C23, C24: 10u; T495D; Mouser Part Number 80-T495D106K035
C29, C30, C35, C36, C39, C40: 0.22u; C0805-0.22u; Manufacturer_Part_Number C0805C224M5VACTU
IC3: FOD814_OPTO_NOSHD; SOP254P1016X385-4N-FOD; Mouser Part Number 512-FOD814SD
IC5: FOD814_OPTO_MEL; SOP254P1016X385-4N-FOD; Mouser Part Number 512-FOD814SD
IC6: AD844_OPAMP_AL; SOIC127P1032X265-16N-AD844; Mouser Part Number 584-AD844JRZ-16-R7
IC7: FOD814_OPTO_AL; SOP254P1016X385-4N-FOD; Mouser Part Number 512-FOD814SD
IC8: AD844_OPAMP_NOSHD; SOIC127P1032X265-16N-AD844; Mouser Part Number 584-AD844JRZ-16-R7
IC10: AD844_OPAMP_MEL; SOIC127P1032X265-16N-AD844; Mouser Part Number 584-AD844JRZ-16-R7
J_AD844: Conn_01x04; PinHeader_1x04_P2.54mm_Vertical
J_FOD814: Conn_01x06; PinHeader_1x06_P2.54mm_Vertical
J_REF192: Conn_01x03; PinHeader_1x03_P2.54mm_Vertical
R15, R19, R23: 820; R_0402_1005Metric
R16, R20, R24: 47; R_0402_1005Metric
R17, R18, R26, R27, R29, R30: 100; R_0402_1005Metric
R22, R28, R34: 100k; R_0402_1005Metric
R25, R31, R35: 1k; R_0402_1005Metric
U2: REF192_NOSHD; R_8_ADI-REF
U3: REF192_AL; R_8_ADI-REF
U4: REF192_MEL; R_8_ADI-REF

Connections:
+5V: C20.1, C22.1 (+), C23.1 (+), C24.1 (+), C28.1, C30.1, C34.1, C36.1, C40.1, IC6.14 (V+), IC8.14 (V+), IC10.14 (V+), R17.2, R26.2, R29.2, U2.2 (VS), U2.3 (*SLEEP), U3.2 (VS), U3.3 (*SLEEP), U4.2 (VS), U4.3 (*SLEEP); also elsewhere on the board
-5V Output: C29.1, C35.1, C39.1, IC6.7 (V-), IC8.7 (V-), IC10.7 (V-); also elsewhere on the board
ADC1_IN0_SINE: IC6.5 (+IN), IC8.5 (+IN), IC10.5 (+IN), J_AD844.4, R15.2, R19.2, R23.2; also elsewhere on the board
ADC1_IN1_OPAMP_NOSHD: IC8.12 (OUTPUT), J_AD844.1, R35.1; also elsewhere on the board
ADC1_IN2_OPAMP_MEL: IC10.12 (OUTPUT), J_AD844.3, R31.1; also elsewhere on the board
ADC1_IN3_OPAMP_AL: IC6.12 (OUTPUT), J_AD844.2, R25.1; also elsewhere on the board
ADC1_IN4_VREF_NOSHD: C19.1, C21.1, J_REF192.1, U2.6 (OUTPUT); also elsewhere on the board
ADC1_IN5_VREF_MEL: C37.1, C38.1, J_REF192.3, U4.6 (OUTPUT); also elsewhere on the board
ADC1_IN6_VREF_AL: C31.1, C32.1, J_REF192.2, U3.6 (OUTPUT); also elsewhere on the board
ADC1_IN10_OPTO_F_NOSHD: IC3.2 (KA), J_FOD814.2, R16.1; also elsewhere on the board
ADC1_IN11_OPTO_E_NOSHD: IC3.3 (E), J_FOD814.1, R18.2; also elsewhere on the board
ADC1_IN12_OPTO_F_MEL: IC5.2 (KA), J_FOD814.6, R20.1; also elsewhere on the board
ADC1_IN13_OPTO_E_MEL: IC5.3 (E), J_FOD814.5, R30.2; also elsewhere on the board
ADC1_IN14_OPTO_F_AL: IC7.2 (KA), J_FOD814.4, R24.1; also elsewhere on the board
ADC1_IN15_OPTO_E_AL: IC7.3 (E), J_FOD814.3, R27.2; also elsewhere on the board
GND: C19.2, C20.2, C21.2, C22.2 (-), C23.2 (-), C24.2 (-), C28.2, C29.2, C30.2, C31.2, C32.2, C34.2, C35.2, C36.2, C37.2, C38.2, C39.2, C40.2, R16.2, R18.1, R20.2, R22.1, R24.2, R27.1, R28.1, R30.1, R34.1, U2.4 (GND), U3.4 (GND), U4.4 (GND); also elsewhere on the board
unnamed: IC3.1 (AK), R15.1
unnamed: IC3.4 (C), R17.1
unnamed: IC5.1 (AK), R19.1
unnamed: IC5.4 (C), R29.1
unnamed: IC6.3 (-IN), R22.2, R25.2
unnamed: IC7.1 (AK), R23.1
unnamed: IC7.4 (C), R26.1
unnamed: IC8.3 (-IN), R34.2, R35.2
unnamed: IC10.3 (-IN), R28.2, R31.2

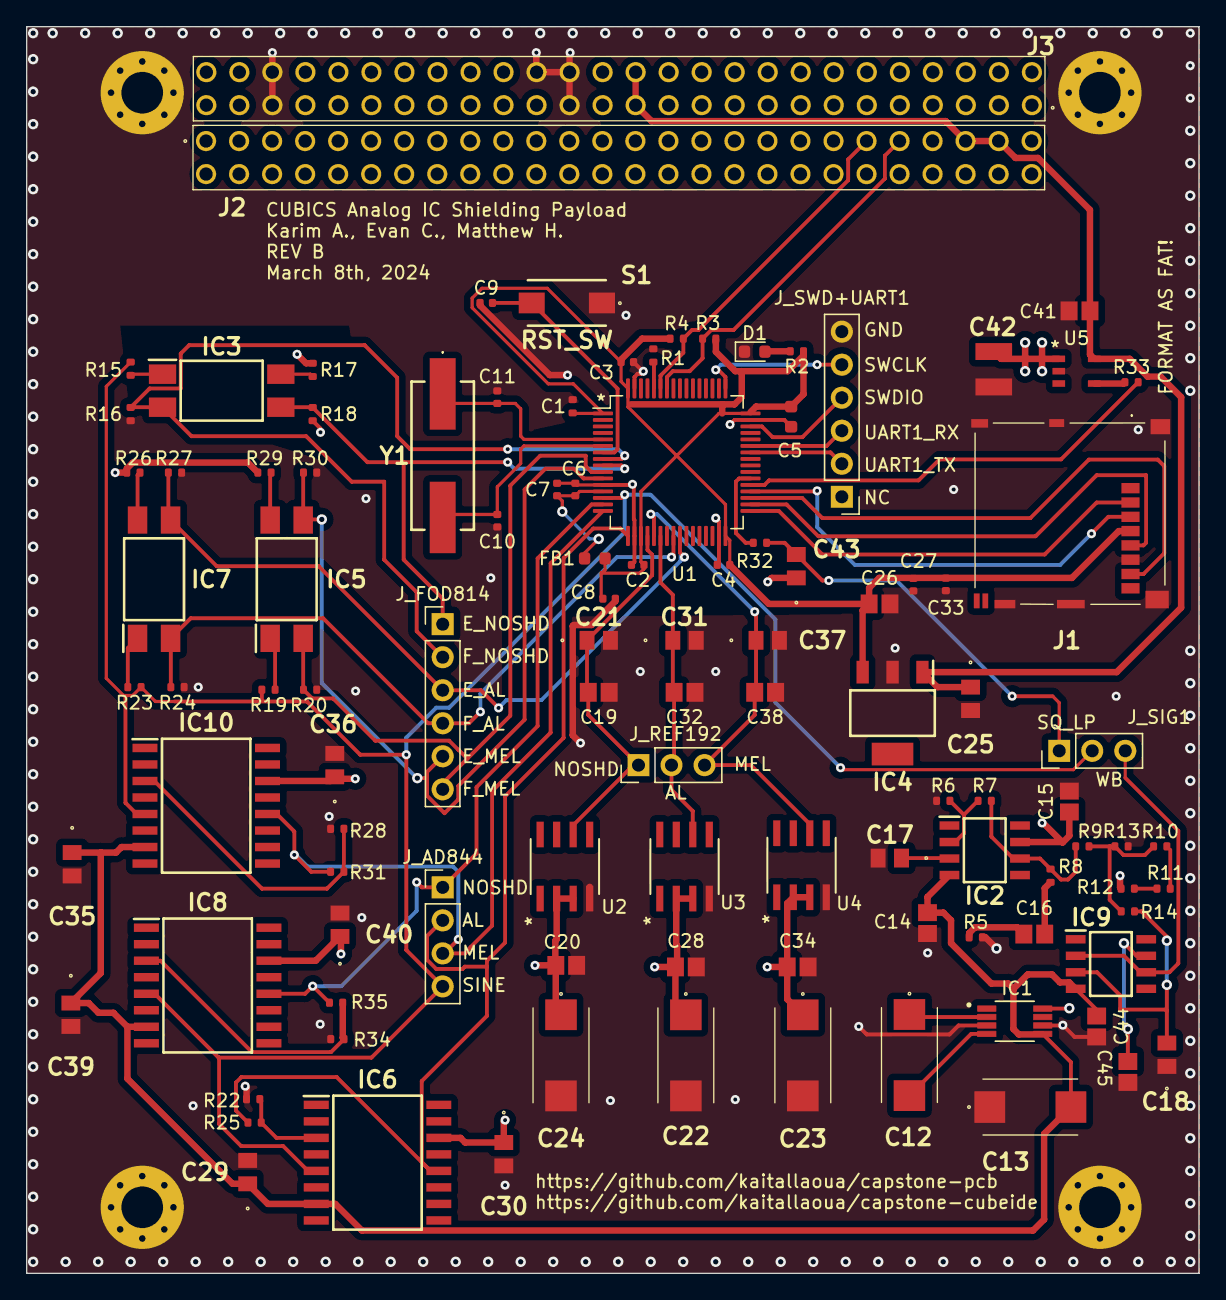
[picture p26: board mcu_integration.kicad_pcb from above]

Board: 4 copper layers, 90.2 x 95.9 mm, 110 parts (0 on the bottom side), 59 nets.

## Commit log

2024-01-31 mcu_integration sch done
    [mcu_integration.kicad_pcb, mcu_integration.kicad_sch]
2024-02-06 mcu integration done, 10x10cm pcb+micro sd+osc
    [ECS-80-18-5PX-GM-TR.stp, mcu_integration.kicad_pcb, mcu_integration.kicad_sch]
2024-02-06 use generic dir (#2)
    [mcu_integration.kicad_pcb]
2024-02-09 Signal gen and - 5 V circuits added (#3)
    I added the two circuits for signal gen and - 5 V all capacitators are speced and in the #links in discord.
    [C0805C103F5GACTU.stp, CAPC220145_88N_KEM.step, Evan_-5V_and_signal_gen.kicad_sch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]
2024-02-13 Implemented IC Test portion (AD844, FOD814, REF192) (#5)
    [AD844ANZ.stp, C0805C105Z5VACTU-1u.stp, C0805C224M5VACTU-0.22u.stp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]
2024-02-14 Added labels for ADC's, change R's and C's values to have more of same parts (#7)
    [mcu_integration.kicad_sch]
2024-02-14 Evan---Adding_PC104_Connector (#8)
    Added the PC104 connector, added global -5v and signal output labels, changed r12 to 330, and added r21 of 150k.
    [Evan_-5V_and_signal_gen.kicad_sch, mcu_integration.kicad_pcb]
2024-02-15 Adding 3.3v reg (#9)
    added 3.3v regulator circuit.
    [Evan_-5V_and_signal_gen.kicad_sch, mcu_integration.kicad_pcb]
2024-02-18 First Major PCB layout and routing (#10)
    * first bulk commit of routing
    * removed about 300 pcb ERC warnings
    * removed all pcb DRC errors/warnings
    * silkscreen: remove part num from inside part, cleanup
    * add silk labels for each pin, my final cleanup
    * remove all errors and suppress unspecified connections warnings in schematic ERC
    ---------
    [Evan_-5V_and_signal_gen.kicad_sch, mcu_integration.kicad_pcb, mcu_integration.kicad_sch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]
2024-02-20 Wire touchup, initial changes (#12)
    * Implemented mosfet, decoupling
    Please review functionality
    * wire placement, inital revisions
    made it more PCB ready with spacing and such
    [DBV0005A-MF.stp, Evan_-5V_and_signal_gen.kicad_sch, mcu_integration.kicad_pcb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]
2024-02-20 MOSFET connections updated (#13)
    * MOSFET connections updated
    updated the MOSFET connection to control the 5V plane and added a separate line going directly to the 3.3V regulator.
    * rotate U5 silk
    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
    [Evan_-5V_and_signal_gen.kicad_sch, mcu_integration.kicad_pcb]
2024-02-22 (accepted by jlc) Updated vias from micro to through hole (#14)
    Please check to ensure there are no more micro vias.
    [mcu_integration.kicad_pcb]
2024-02-27 update README with images, add BOM, schematic pdf, update evan sch title (#15)
    [Evan_-5V_and_signal_gen.kicad_sch]
2024-03-03 Karim start 2nd rev (#16)
    * done layout/ratsnet
    * 95% of second rev done, just two errors
    [Evan_-5V_and_signal_gen.kicad_sch, mcu_integration.kicad_pcb, mcu_integration.kicad_sch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]
2024-03-06 fix +5v connection, make final via (#17)
    * fix +5v connection, make final via
    * connect mcu 3.3vreg to +5v_ext so it always has power
    [Evan_-5V_and_signal_gen.kicad_sch, mcu_integration.kicad_pcb]
2024-03-11 (accepted by jlc rev B) Karim rev2 cleanup (#18)
    * fixed all errors and warnings, silk fixed
    * add names to project
    * misc cleanup
    * TL766 footprint fixed
    * proper holes added
    * hole sizing done, evan cap fix
    * mcu square wave sine header, more space for ic's should be ready for order
    * ready for jlcpcb
    * cleanup README
    * close kicad before commit
    [ESQ-126-39-L-D.stp, Evan_-5V_and_signal_gen.kicad_sch, MS128-10C.step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]
2024-03-12 soldermask applied to ic1 (#19)
    [mcu_integration.kicad_pcb]
2024-03-13 rotate sd 180 since was wrong, cleanup, add gnd vias on edge (#20)
    [mcu_integration.kicad_pcb]
2024-03-17 Added-Voltage-follower-and-Changed-opto-resistor-values (#21)
    Added the voltage follower circuit to the signal gen. Changed the R values on the optoisolator circuit.
    [Evan_-5V_and_signal_gen.kicad_sch, mcu_integration.kicad_pcb, untitled.kicad_sch]
2024-03-23 clean evan schematic (#22)
    * clean evan schematic
    * update schematic pdf
    [Evan_-5V_and_signal_gen.kicad_sch]
